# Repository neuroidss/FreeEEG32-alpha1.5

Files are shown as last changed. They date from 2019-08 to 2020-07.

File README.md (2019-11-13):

# FreeEEG32 + alpha1.5
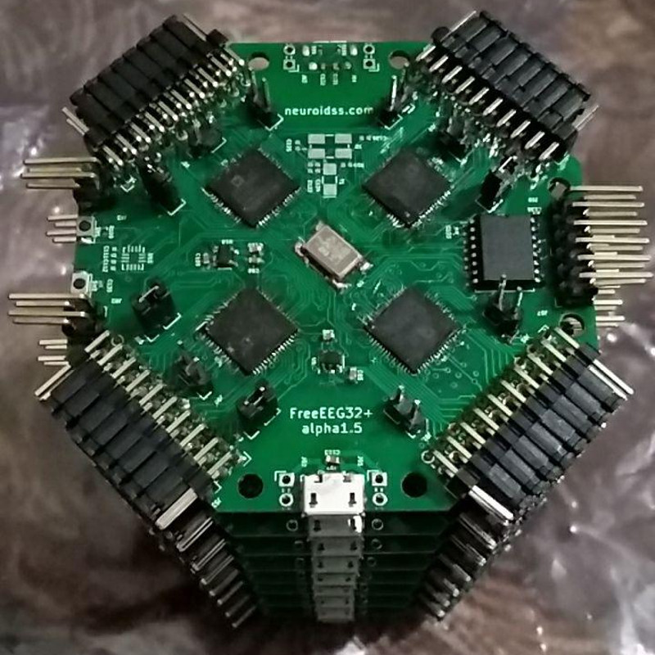
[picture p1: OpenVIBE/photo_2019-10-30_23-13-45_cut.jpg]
8x FreeEEG32 + alpha1.5

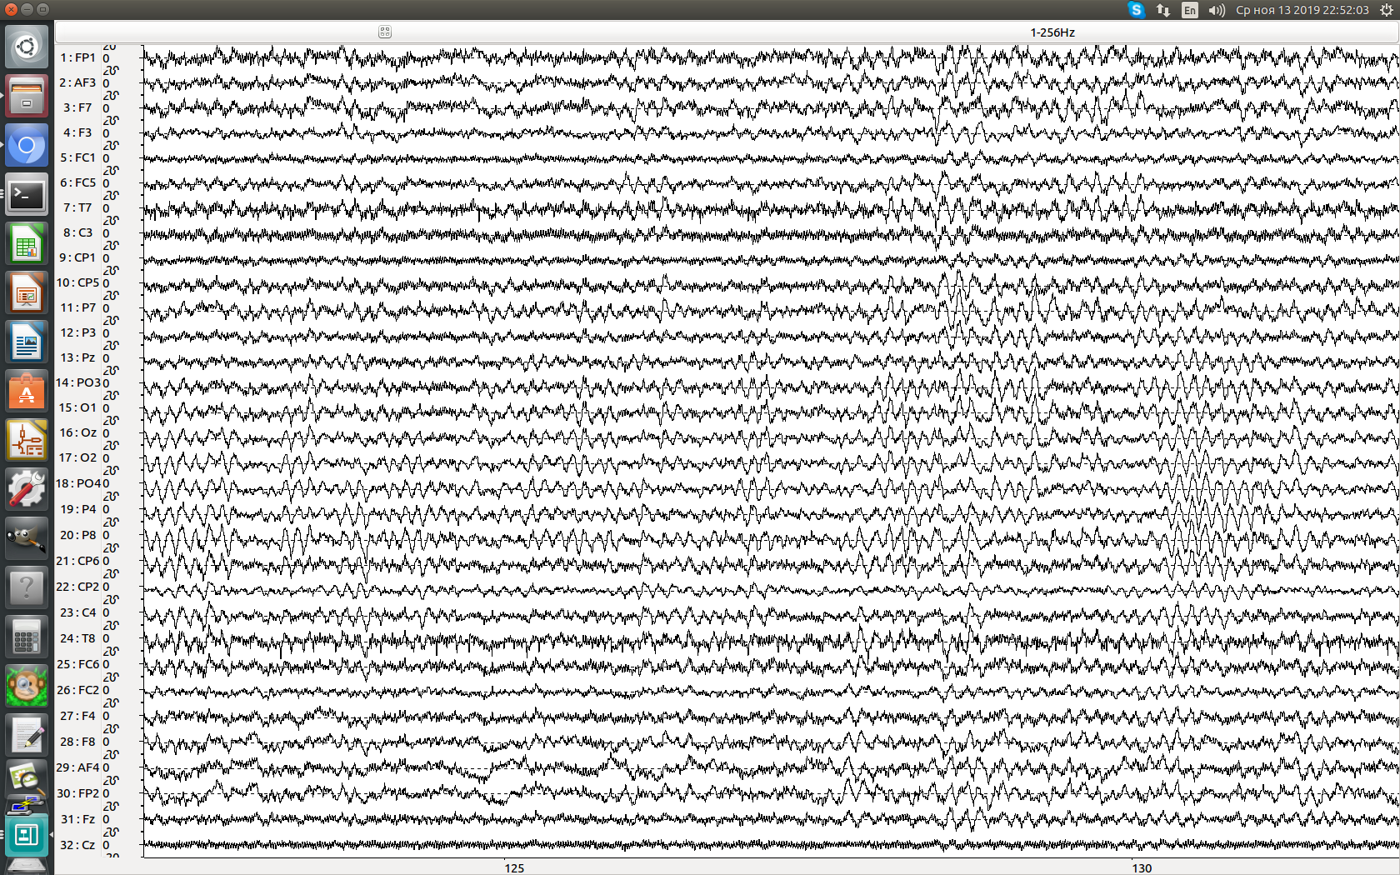
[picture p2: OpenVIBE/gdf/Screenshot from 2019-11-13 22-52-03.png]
OpenVIBE FreeEEG32 + alpha1.5

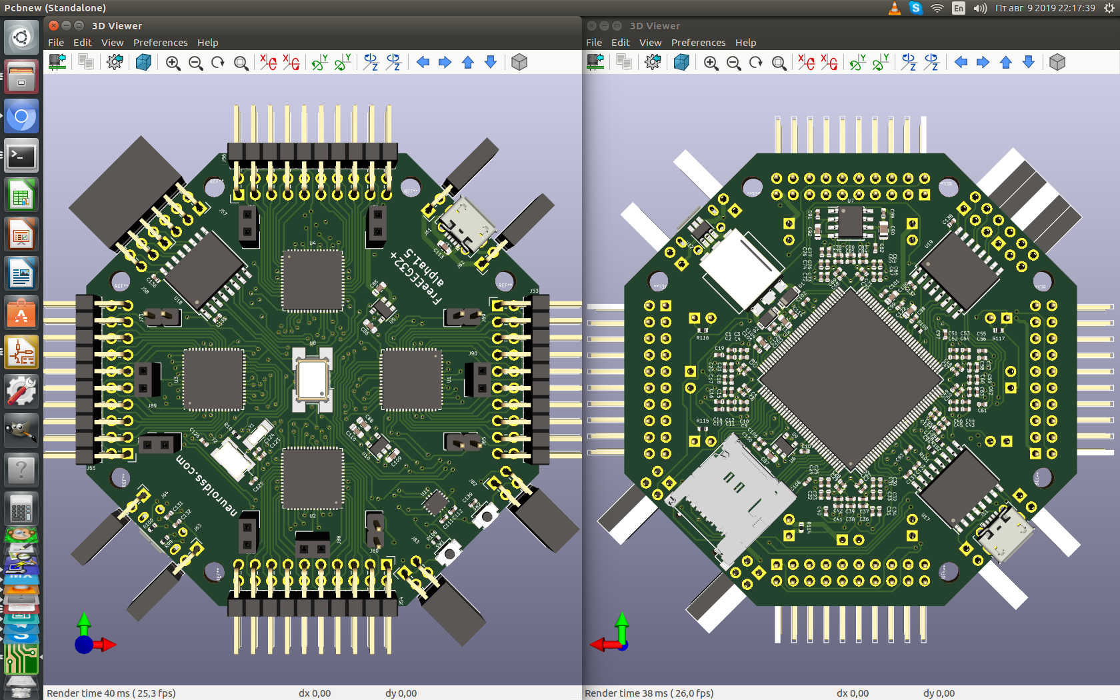
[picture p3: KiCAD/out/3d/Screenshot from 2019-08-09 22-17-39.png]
KiCAD FreeEEG32 + alpha1.5

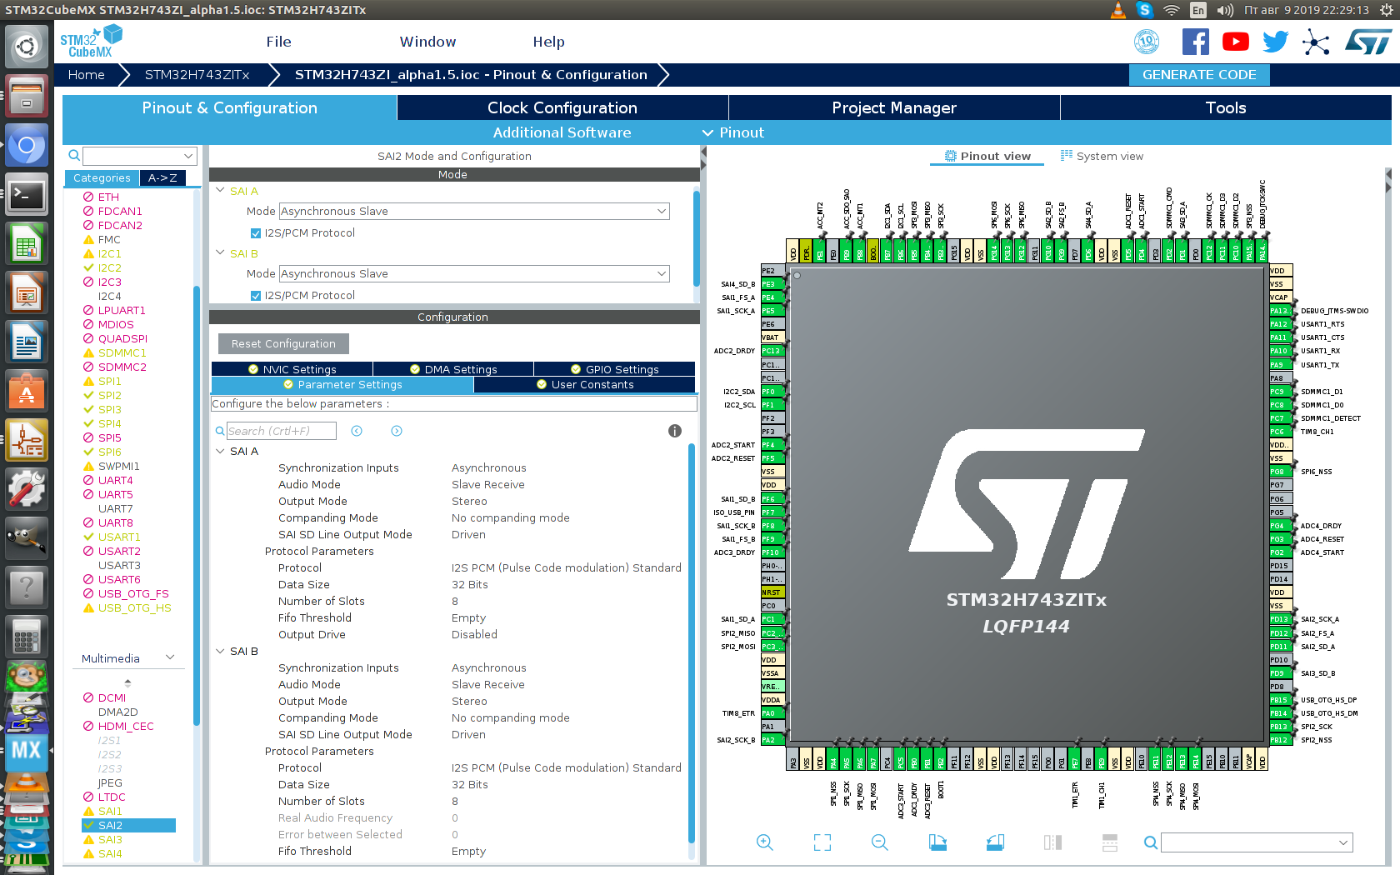
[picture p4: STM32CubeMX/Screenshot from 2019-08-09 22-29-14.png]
STM32CubeMX FreeEEG32 + alpha1.5

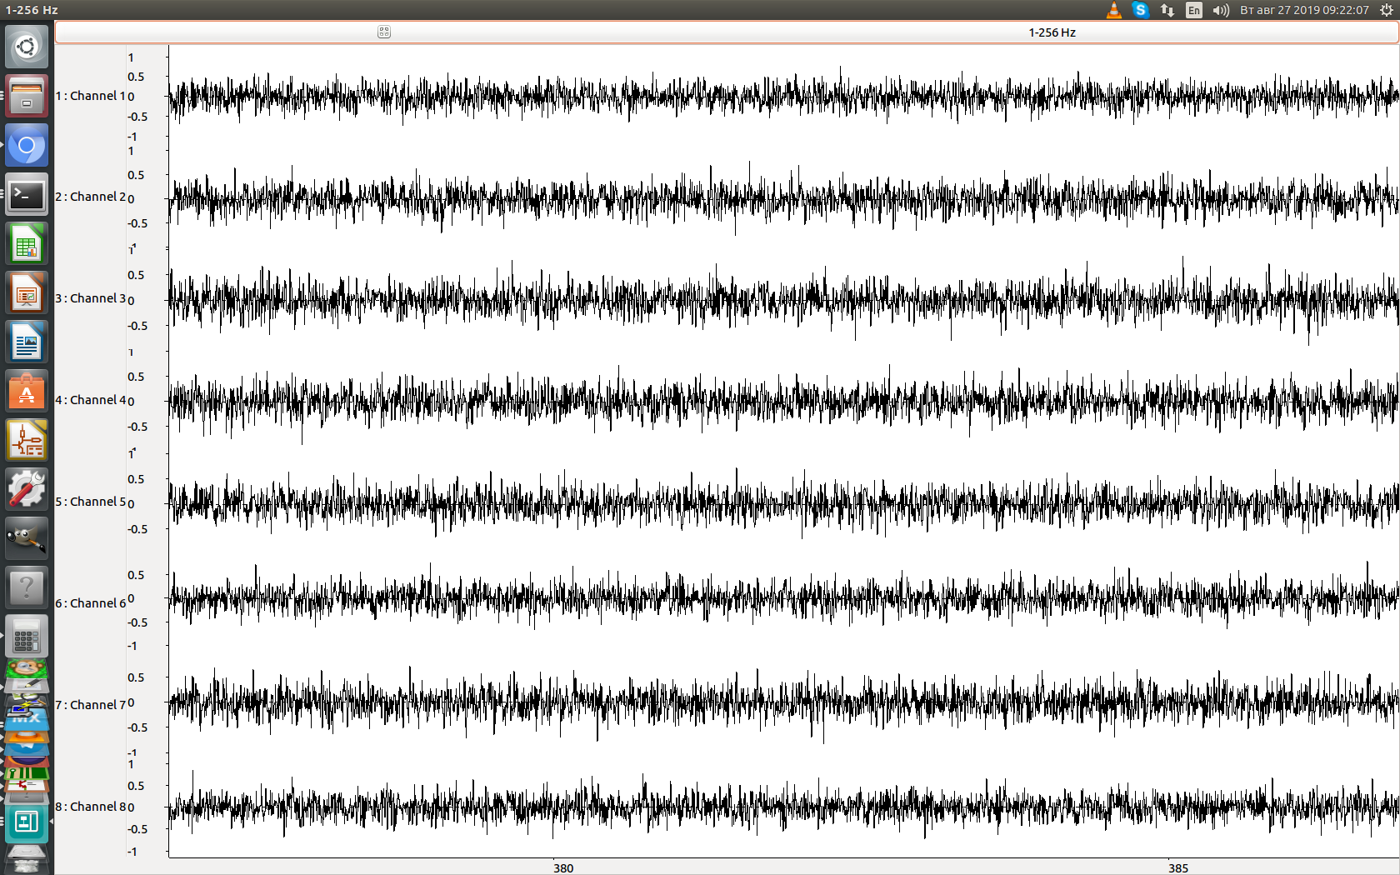
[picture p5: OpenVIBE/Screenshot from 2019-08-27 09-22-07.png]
OpenVIBE FreeEEG32 + alpha1.5

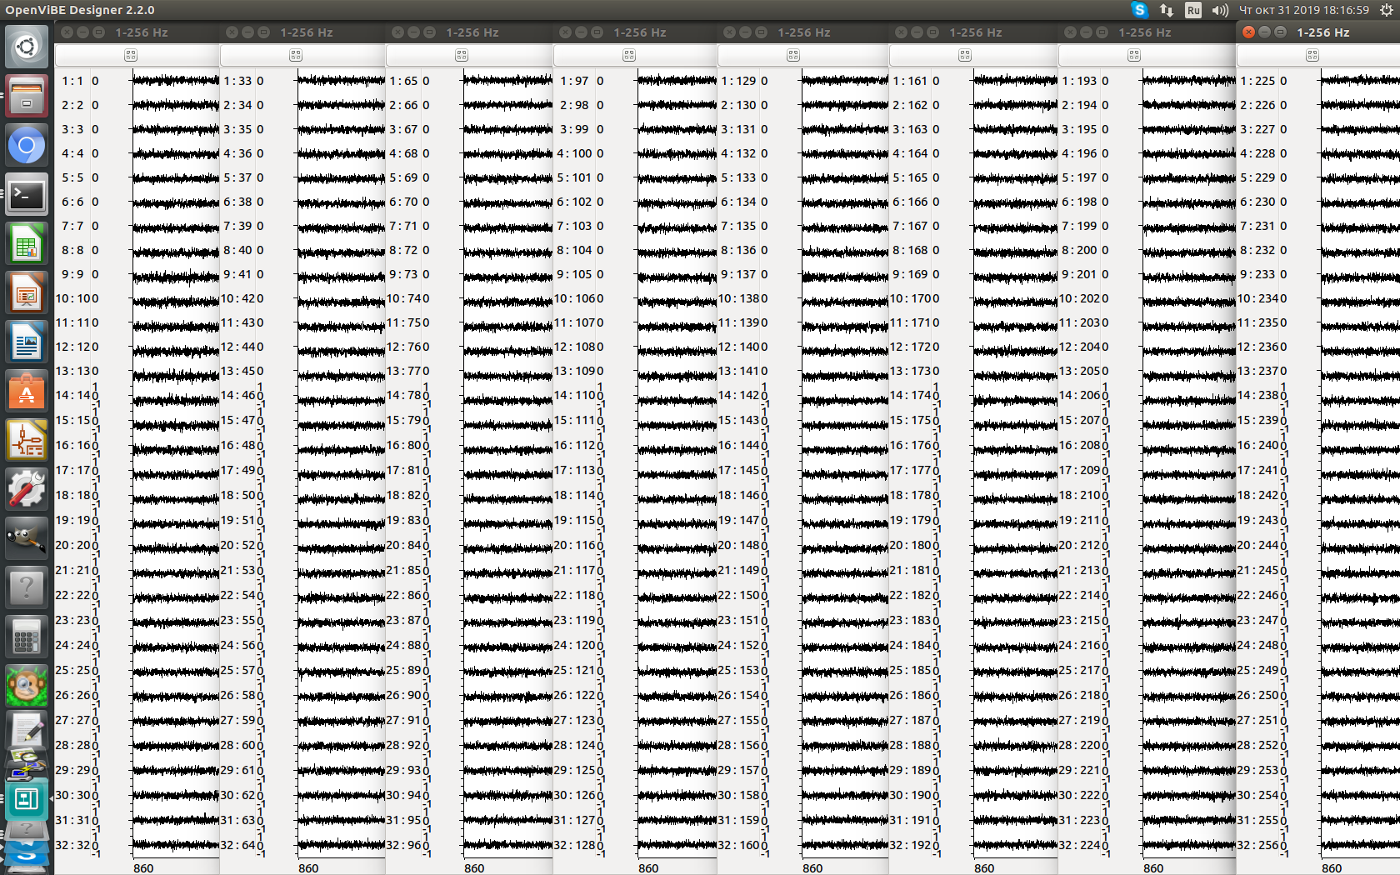
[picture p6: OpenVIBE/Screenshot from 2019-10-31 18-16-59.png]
OpenVIBE 8x FreeEEG32 + alpha1.5


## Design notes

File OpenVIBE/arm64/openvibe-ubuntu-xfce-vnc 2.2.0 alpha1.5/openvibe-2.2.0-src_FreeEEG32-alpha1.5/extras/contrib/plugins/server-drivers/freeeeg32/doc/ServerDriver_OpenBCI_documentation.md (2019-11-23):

OpenViBE logo

OpenBCI logo

# OpenBCI driver for OpenViBE documentation #

(documentation stands for [OpenViBE][OpenViBE] **1.2.0-OpenBCI-RC1**)

## Welcome ##

Welcome in the documentation of the [OpenBCI][OpenBCI] driver for [OpenViBE][OpenViBE]. This document gives you step by step details on how to configure your system, hardware and software to get the best possible experience. For further details about OpenBCI and OpenViBE, please refer to their [respective][OpenBCI] [documentation][OpenViBE].

## Getting Started ##

This section gives guidelines on how to set-up your environment configuration to get the best experience using [OpenBCI][OpenBCI] with [OpenViBE][OpenViBE]

### Linux ###

In order to use the [OpenBCI][OpenBCI] driver on Linux, you need to be granted read/write access to the serial port that is used to communicate with the dongle. Unfortunately, this does not come as a standard configuration on many Linux distributions and you will need to configure your setup so that the user is granted these access. On [Ubuntu][UbuntuDotCom] and its derivative, as well as on [Debian][DebianDotOrg], this can simply be achieved by adding the user to the `dialog` group with the following command :

> sudo adduser *username* dialout

Please note that you may need to close and reopen the session for changes to take effect.

On [Fedora][FedoraDotOrg] and its derivative, a similar command should be used to add the user in the `dialout` group :

> sudo usermode -a -G dialout *username*

Again, please note that you may need to close and reopen the session for changes to take effect.

### Windows ###

It is necessary to walk through a litlle bit of configuration to have the best experience with [OpenBCI][OpenBCI] and [OpenViBE][OpenViBE] on Windows. Indeed, when Windows first installs a serial port, its default configuration is not optimal for realtime streaming of the data. It especially configures large buffering and latencies, causing delays in the communication which eventually lead in delays in the acquired signals. While this only delays the detection of Motor Imagery or SSVEP tasks by a few hundreds of milliseconds, this also delays the ERP (eventually leading to a misdetection) and in all cases, alters the neurophysiological validity of the acquired data by a significant fraction. Consequently, it is recommended to configure the serial ports so that they are suitable for realtime use.

Note that this configuration is necessary each time Windows creates a new serial port. This may unfortunately happen **every time** you move the dongle on a new USB port on the computer !

In order to open the configuration dialog of the serial port, please follow these steps:

- Right click on the `Computer` icon and chose `Manage`
- After the `Computer Management` tool is opened, browse the tree in the left pane to the `Device Manager` section
- After the `Device Manager` tree is opened, browse in the right pane to the `Ports (COM & LPT)` section
- Then double click your port (in my case, `USB Serial Port (COM3)`

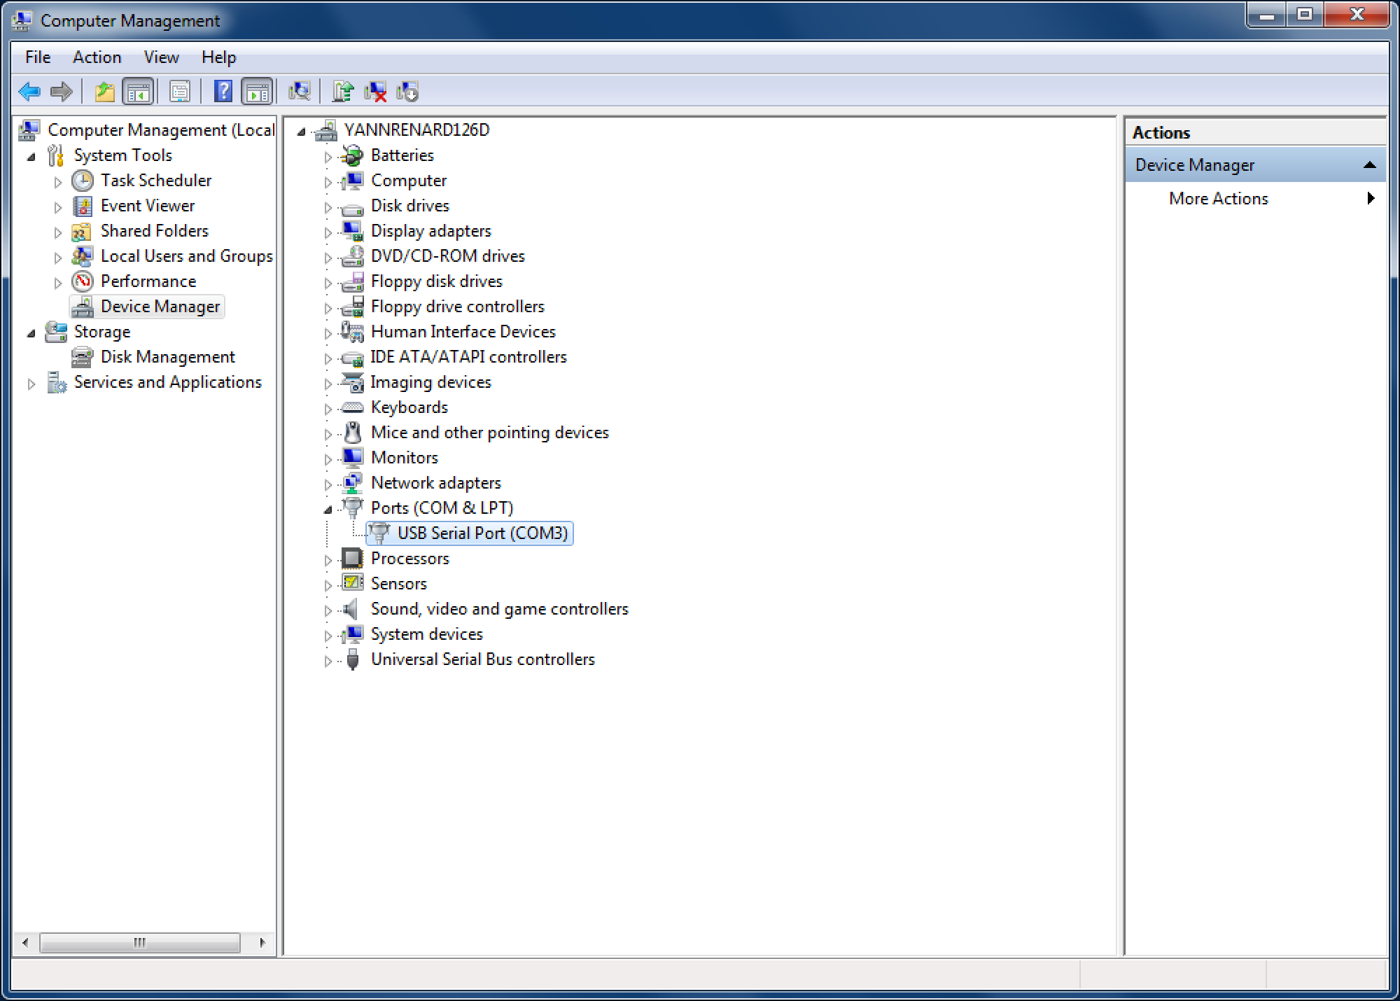
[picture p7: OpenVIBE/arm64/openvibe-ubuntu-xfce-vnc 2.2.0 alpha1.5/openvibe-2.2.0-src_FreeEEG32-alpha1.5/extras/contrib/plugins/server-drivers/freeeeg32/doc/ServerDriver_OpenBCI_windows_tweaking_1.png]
The Windows Device Manager


- In the `USB Serial Port Properties` dialog, go to the `Port Settings` tab and click `Advanced`

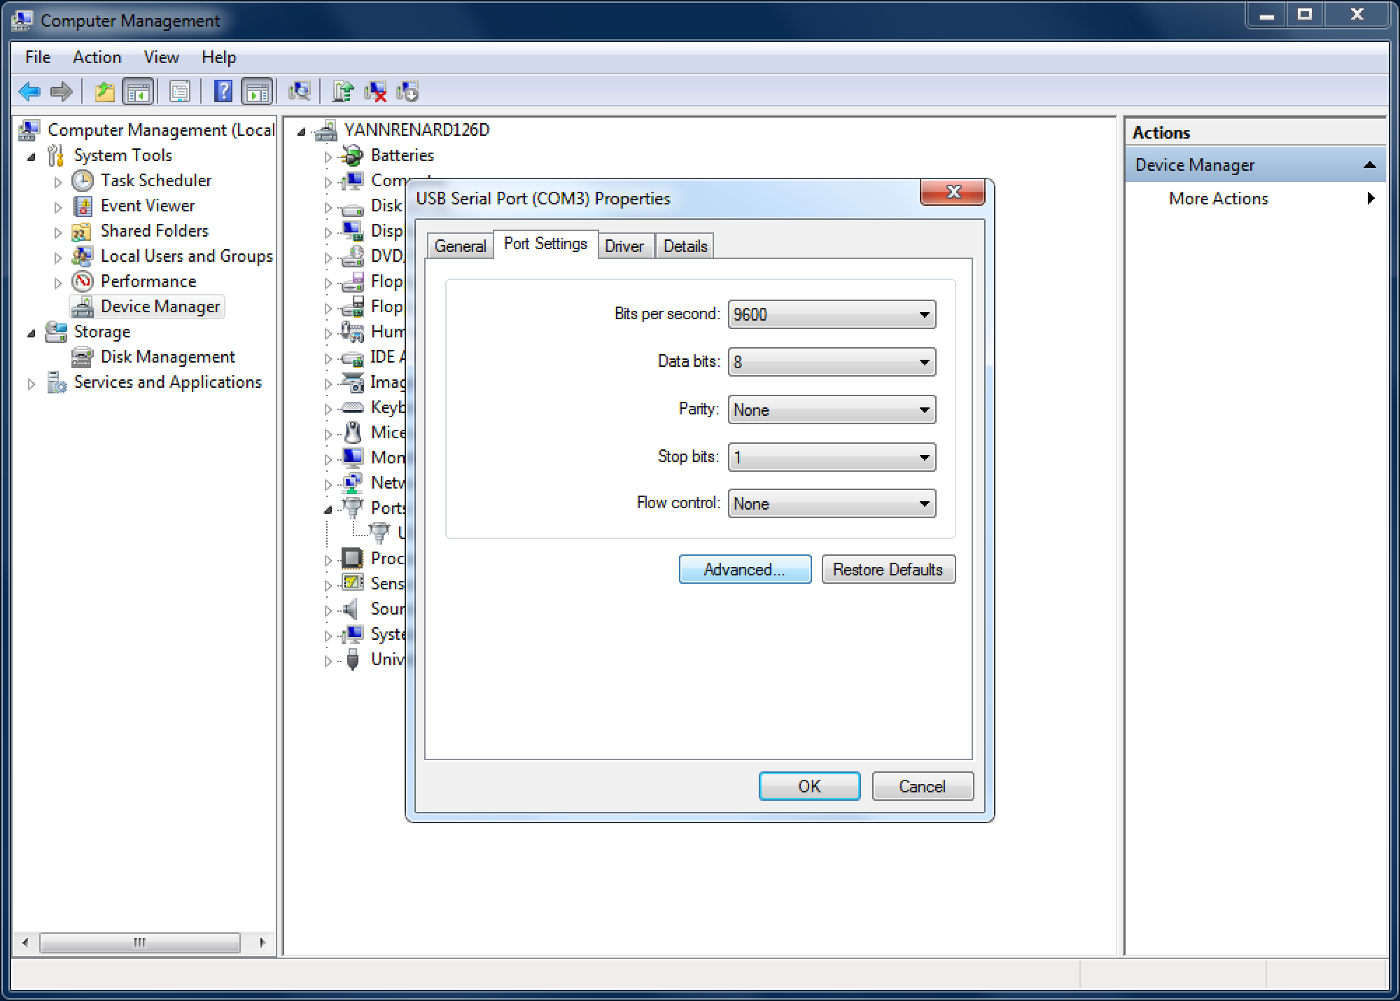
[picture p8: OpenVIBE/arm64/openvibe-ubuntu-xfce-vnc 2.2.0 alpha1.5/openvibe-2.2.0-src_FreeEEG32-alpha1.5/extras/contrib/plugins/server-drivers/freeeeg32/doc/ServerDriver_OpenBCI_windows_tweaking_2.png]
The Port Settings dialog


- This opens the `Advanced Settings for your COM port`

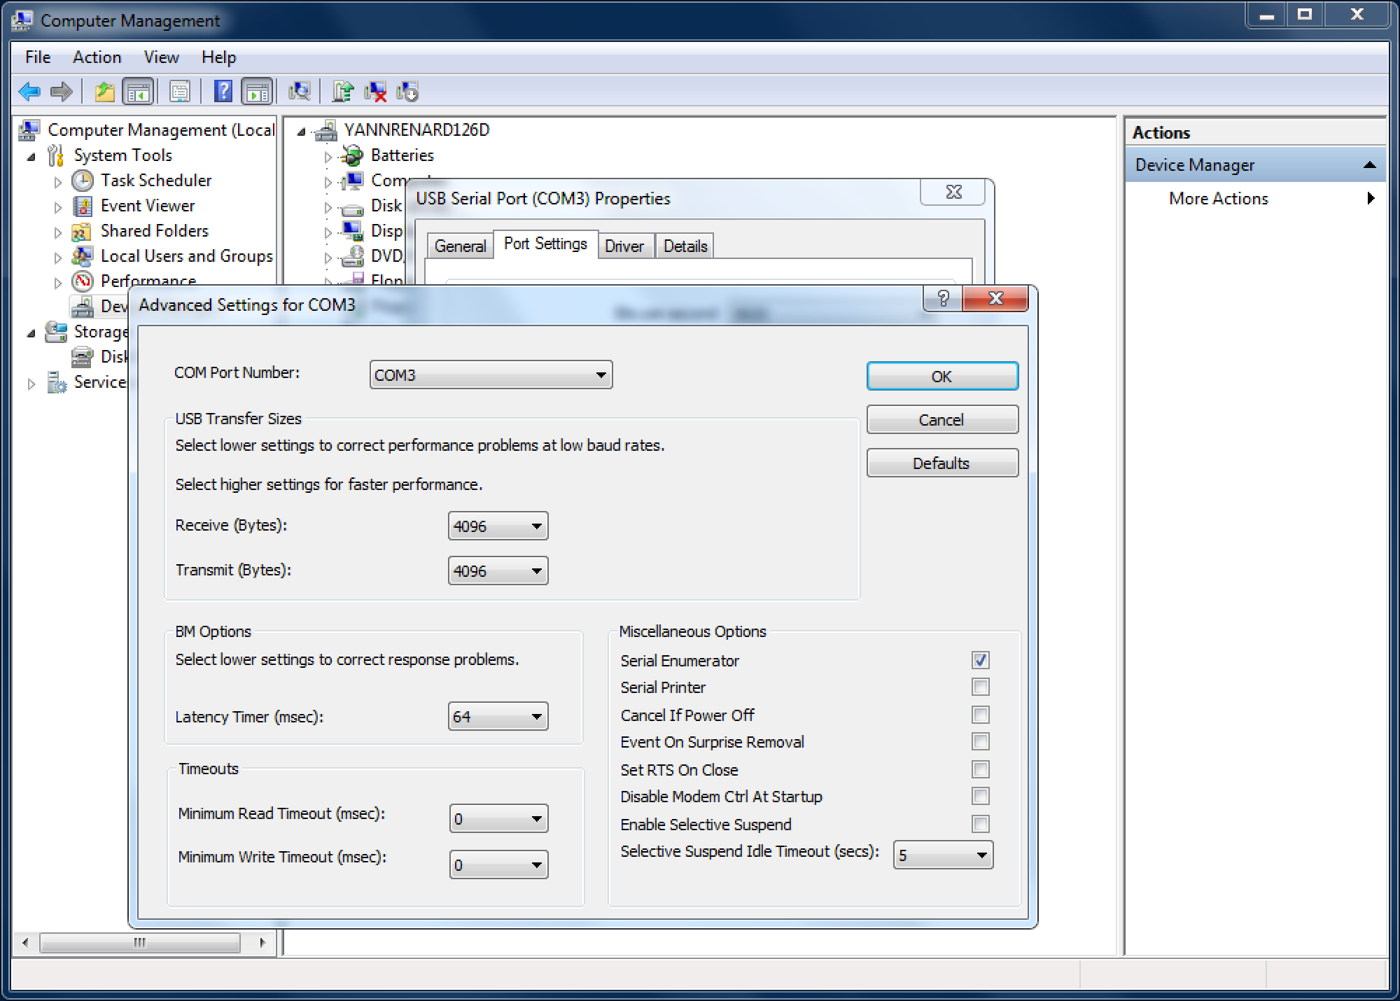
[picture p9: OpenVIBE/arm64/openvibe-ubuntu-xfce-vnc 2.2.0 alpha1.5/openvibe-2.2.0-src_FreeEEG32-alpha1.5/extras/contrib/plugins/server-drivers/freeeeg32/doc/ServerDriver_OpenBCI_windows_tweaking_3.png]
The Advanced Port Settings dialog


From this window, there are three settings we need to change :

- The `Receive` and `Transmit` settings of the `USB Transfer Sizes` section should both be changed from 4096 to **64** as this will reduce the time taken by the OS to deliver the data to either the dongle or the [OpenViBE][OpenViBE] driver
- The `Latency Timer` of the `BM Options` section should be reduced down to **1** as this will dramatically reduce the latency induced by the OS.

After you changed the settings as shown on the following figure, please click `OK`.

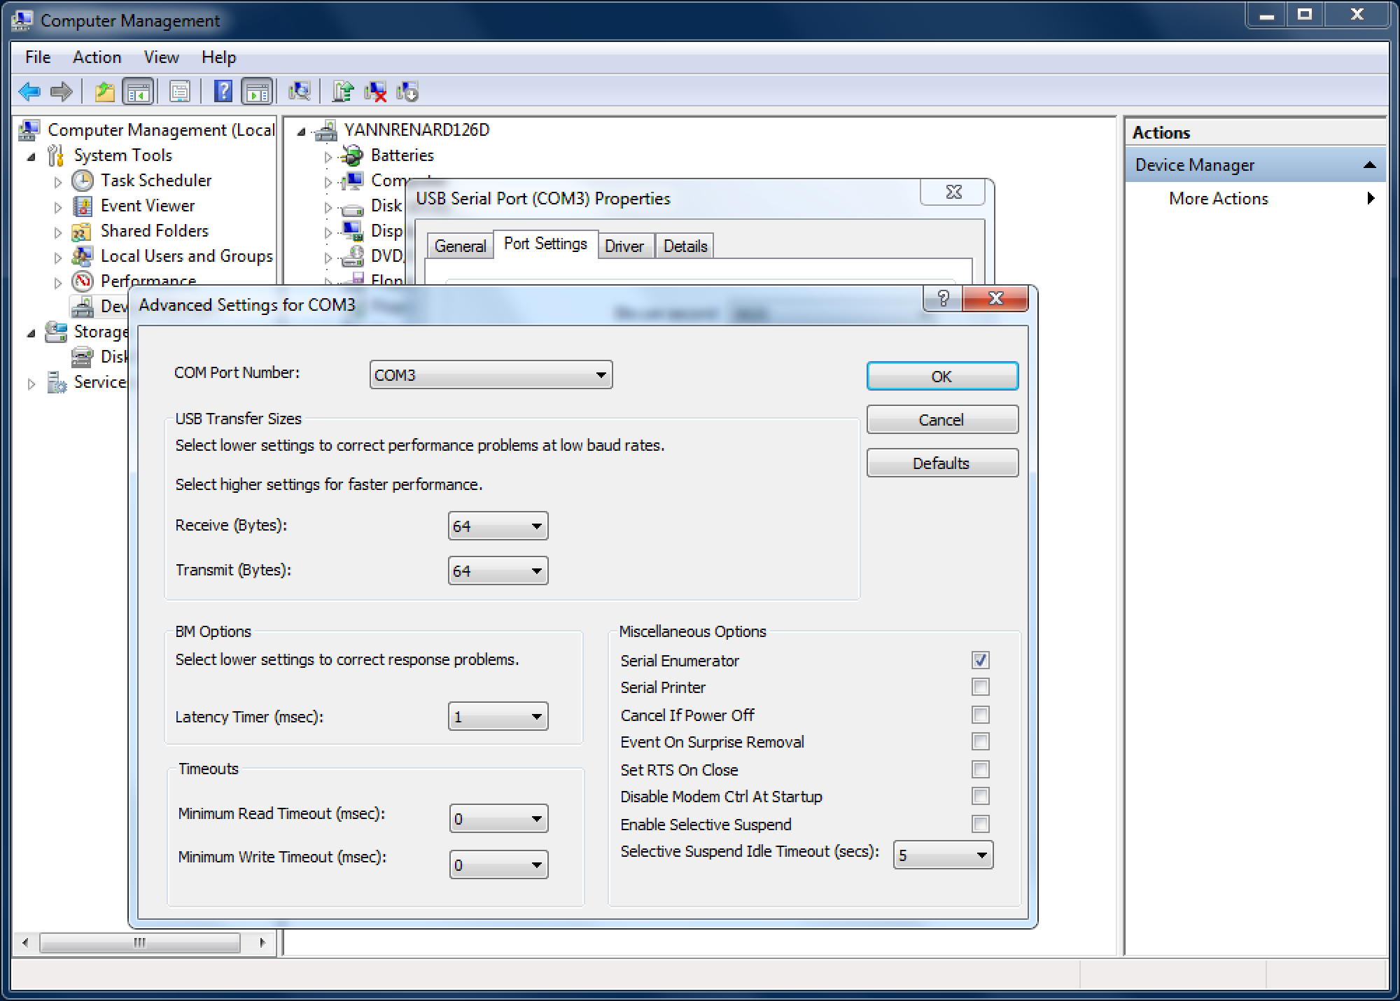
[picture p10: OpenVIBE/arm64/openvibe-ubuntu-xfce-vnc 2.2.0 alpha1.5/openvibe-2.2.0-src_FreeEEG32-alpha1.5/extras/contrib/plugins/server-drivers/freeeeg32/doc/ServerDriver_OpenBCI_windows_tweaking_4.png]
The tweaked configuration of COM ports to have best experienece with OpenViBE and OpenBCI


It is *not necessary* to restart the computer for the changes to take effect.

## Configuration ##

The configuration dialog of the [OpenBCI][OpenBCI] driver comes with a number of settings that one can change or pick depending on his preference.

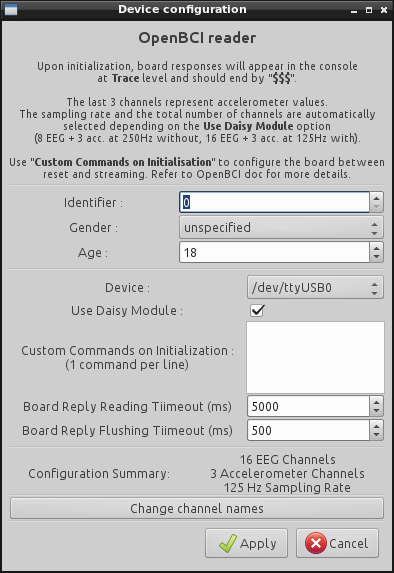
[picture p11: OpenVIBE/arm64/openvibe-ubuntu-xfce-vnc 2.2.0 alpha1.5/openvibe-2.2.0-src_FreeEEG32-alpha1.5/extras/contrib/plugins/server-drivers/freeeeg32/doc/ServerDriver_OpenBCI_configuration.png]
The OpenBCI configuration dialog


The following table documents each option that is specific to the [OpenBCI][OpenBCI] device. Please refer to the [OpenViBE documentation][OpenViBEDoc] for anything generic to the [OpenViBE][OpenViBE] Acquisition Server.

| Option | Default Value | Documentation |
| :---: | :---: | :---|
| **Device** | *empty* | This allows you to pick a serial port to connect on. The drodown list shows the serial ports that can currently be opened on this computer. If no port is found, the mention *No valid serial port* is shown in this list. If you cannot find your device in this list, please refer  . |
| **Use Daisy Module** | *false* | This allows you to configure the daisy module. Four cases should be considered. 1/ if the daisy module is present and this option is set to **true**, then the device will turn to 16 channels samples 125 Hz. 2/ if no daisy module is present and this option is set to **false**, then the device will turn to 8 channels, 250 Hz. 3/ if the daisy module is **not present** on the board and this option is set to **true**, then the initialization of the driver will **fail**. 4/ if the daisy module is **present** on the board and this option is set to **false**, the daisy module will be disabled and the acquisition will be done as if the daisy module was not present on the board, turning the device back to 8 channels sampled at 125 Hz. |
| **Custom Command On Initialization** | *empty* | This option contains additional commands to send to the device at initialization. You must use one line per command, some command may contain multiple characters. For details about the commands, please refer to the [OpenBCI protocol documentation][OpenBCIProto]. Be advised that this will increase the delay of initialization by an order of magnitude that is a direct relation of the number and types of commands you want to add. Finally, not all the commands take the same time to be executed, if you include custom commands, you should consider adjusting the timeout values. |
| **Board Reply Reading Timeout** | 5000 | This allows to define the maximum time until reading a reply from the board after sending a command times out. Many commands end with a **\$\$\$** pattern, which can handily be captured and release the waiting loop when reading the board reply, but not all the commands have this **\$\$\$** pattern. Consequently, it is necessary to have a timeout for the other commands. The default value has been chosen to behave well even with custom commands that need a long time to reply such as **?**. If you don't use such command in your *Custom Command On Initialization*, you may reduce that delay. But be aware that if you reduce it too much, the driver may miss the **\$\$\$** pattern even though the board has sent it, resulting in unexpected behavior. |
| **Board Reply Flushing Timeout** | 500 | This option allows to flush and get rid of the streaming buffer. This is especially used when the driver asks the board to stop streaming and makes the streaming state absolutely clean when the driver needs to send a new command after stopping the streaming. You may reduce this value to make (re)connection faster, but if the buffer came not to be completely flushed, the remaining would be taken as the begining of the next command and this may result in unexpected behavior. |

The Configuration Summary gives information on the current configuration, especially the number of channels and the sampling rate of the device.

## Advanced Configuration ##

In addition to the above settings, another few settings are available to the user as advanced configuration. They are not exposed in the GUI and should be directly set in the [OpenViBEConfig][OpenViBE configuration] file instead. Refere to the [Configuration Manager section][OpenViBEConfig] of the [OpenViBE documentation][OpenViBEDoc] for further details on the configuration file format, location and others.

| Token | Default Value | Documentation |
| :---: | :---: | :---|
| **AcquisitionDriver OpenBCI MissingSampleDelayBeforeReset** | *1000* | This defines the size of the window to continuously monitor reception of samples from the driver. If no sample is received within that timeframe, the board is requested to stop and restart streaming. While the non-reception of samples from the board may reflect an unexpected state in the board, this strategy seems to sometimes recover and let the streaming go back to normal. The default value allows a good compromise between dealing with buffering and actual transmission delays and recovering fast when something goes wrong. If you experience such unstability in the transmision, we recommend that you first explore anything that may (in)directly affect the quality of the transmission before tweaking this setting. |
| **AcquisitionDriver OpenBCI DroppedSampleCountBeforeReset** | *5* | This defines the number of sample loss events until a recovery is attempted. It happens that the board gets in an unstable state where some sample would be missing in the stream. Stopping and restarting the streaming has proved to recover well. The default setting has been set so that a few occasional sample loss may occur (due to e.g. quality transmission) and be corrected by the drift correction process, while not waiting too long to attempt recovery when too many sample are lost. |
| **AcquisitionDriver OpenBCI DroppedSampleSafetyDelayBeforeReset** | *1000* | This defines a sefety delay where no reset should be attempted because of sample loss (see **AcquisitionDriver OpenBCI DroppedSampleCountBeforeReset**). This prevents a reset on the first sample where the driver synchronises with the streaming protocol and may miss a few samples until it is perfectly synced with the header and tail of the protocol frame. |

[FedoraDotOrg]: http://www.fedora.org
[UbuntuDotCom]: http://www.ubuntu.com
[DebianDotOrg]: http://www.debian.org

[OpenViBE]: http://openvibe.inria.fr
[OpenViBEDoc]: http://openvibe.inria.fr/documentation-index
[OpenViBEConfig]: http://openvibe.inria.fr/the-configuration-manager
[OpenViBELogo]: http://openvibe.inria.fr/openvibe/wp-content/themes/openvibe/images/openvibe-banner.png

[OpenBCI]: http://docs.openbci.com
[OpenBCIProto]: http://docs.openbci.com/software/01-OpenBCI_SDK
[OpenBCILogo]: http://openbci.com/community/wp-content/uploads/2015/09/logo_wide_web_borders_BIG-copy-1024x137.png

[WindowsTweaking1]: ServerDriver_OpenBCI_windows_tweaking_1.png
[WindowsTweaking2]: ServerDriver_OpenBCI_windows_tweaking_2.png
[WindowsTweaking3]: ServerDriver_OpenBCI_windows_tweaking_3.png
[WindowsTweaking4]: ServerDriver_OpenBCI_windows_tweaking_4.png
[DriverDialog]: ServerDriver_OpenBCI_configuration.png

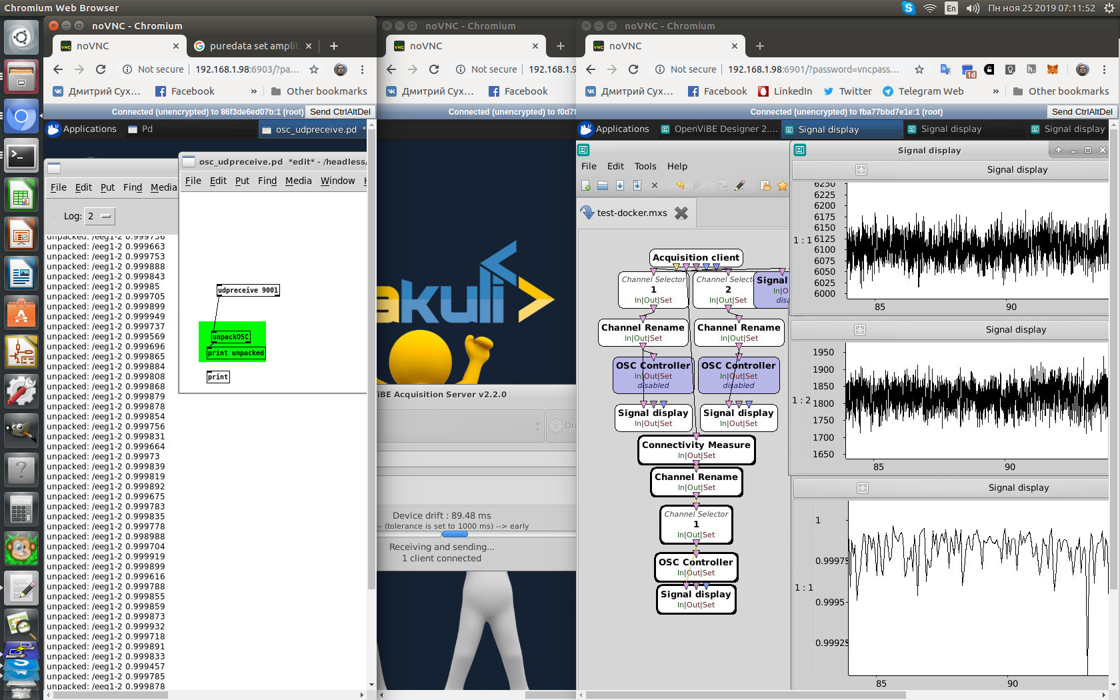
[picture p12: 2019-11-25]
OpenVIBE/Screenshot from 2019-11-25 07-11-53.png

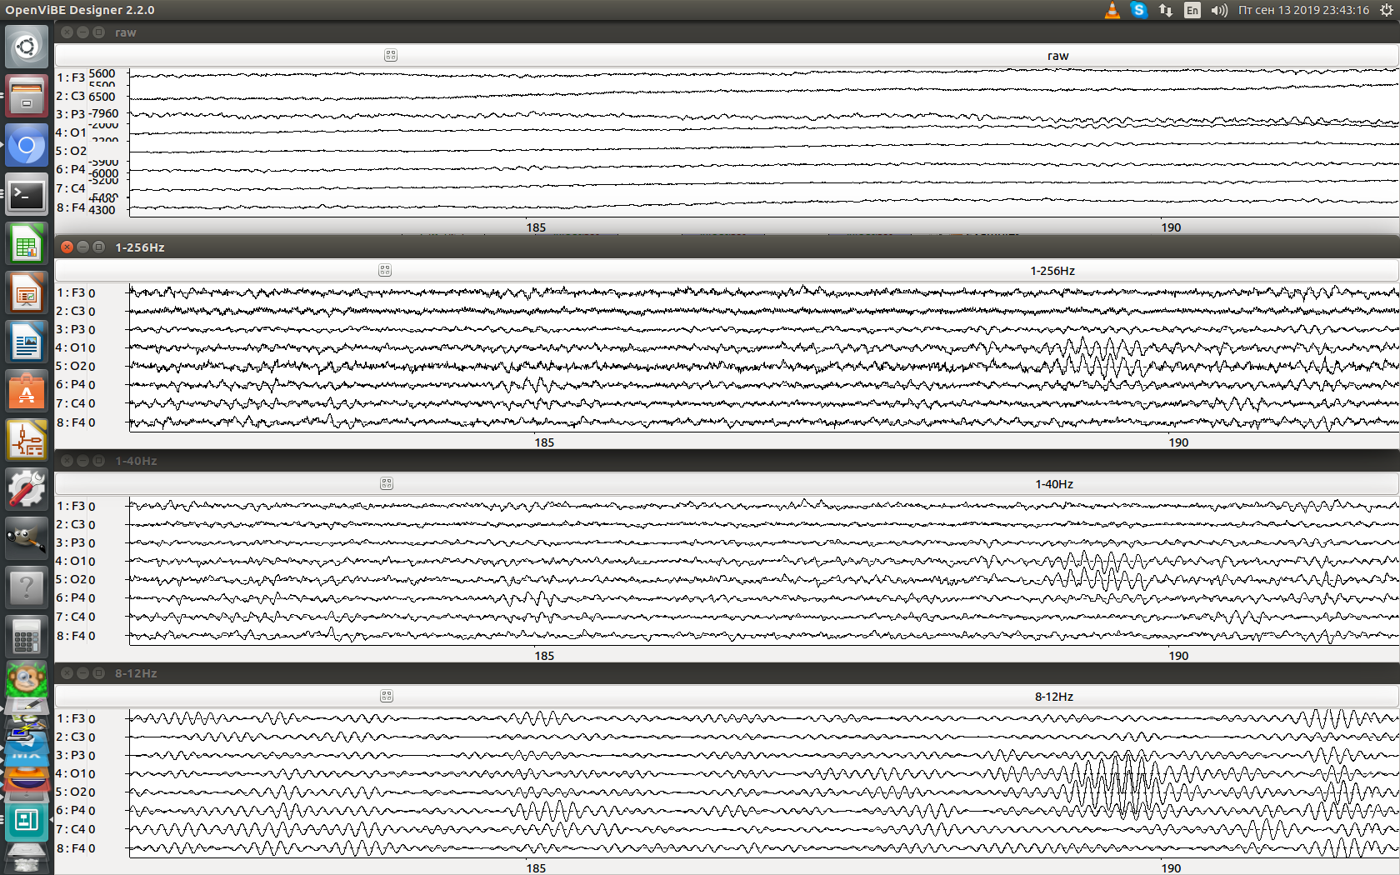
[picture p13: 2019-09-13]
OpenVIBE/gdf/Screenshot from 2019-09-13 23-43-16.png

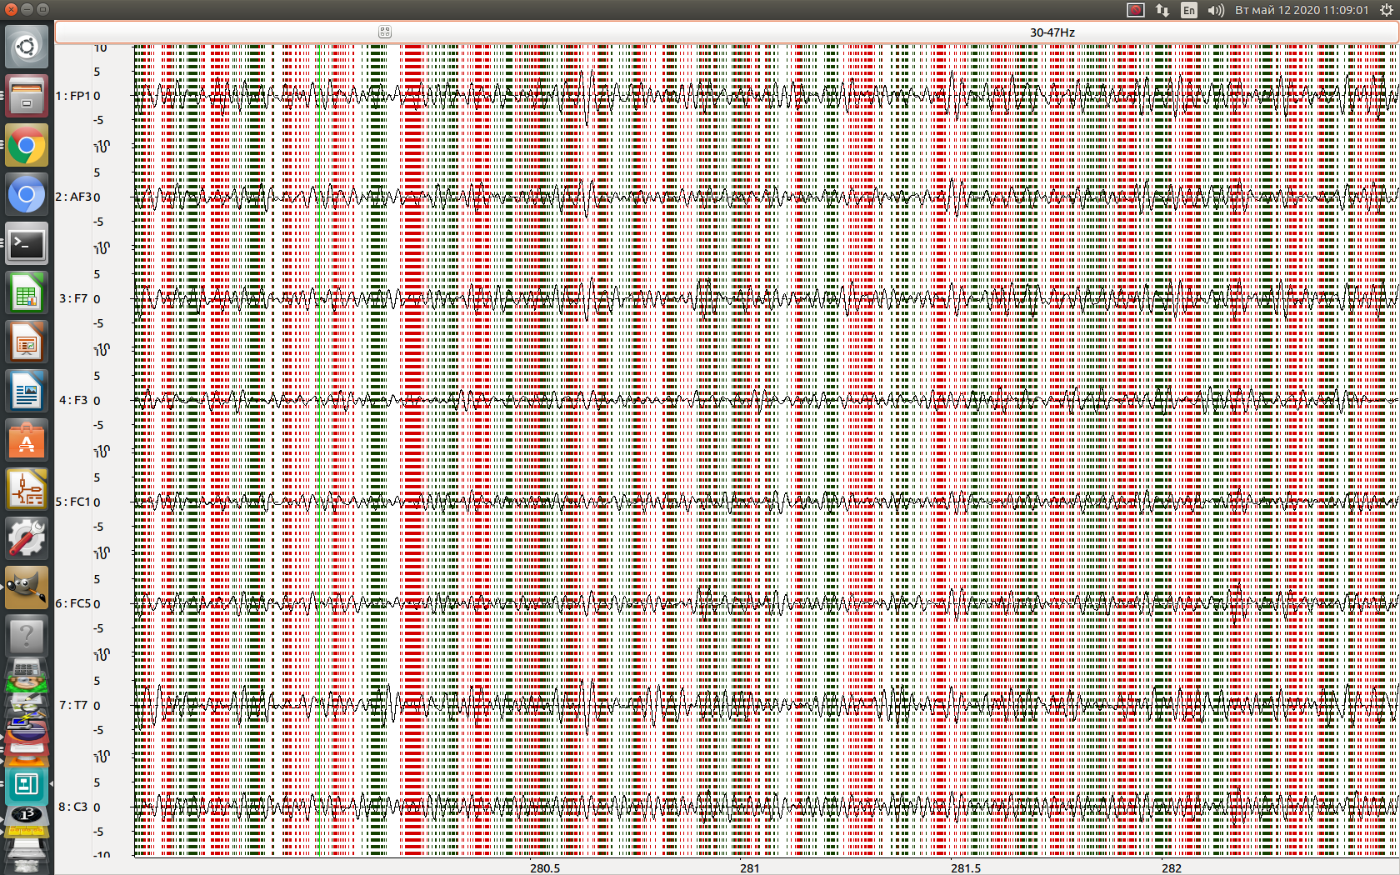
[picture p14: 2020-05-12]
theta&gamma2octave/Screenshot from 2020-05-12 11-09-02.png

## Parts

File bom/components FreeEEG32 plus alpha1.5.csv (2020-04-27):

Designator | Manufacturer Part Number or Seeed SKU | Qty | Link | Description | alt
U1,U2,U4,U3 | AD7771BCPZ | 4 |  | IC ADC 24BIT SIGMA-DELTA 64LFCSP
U7 | ADR4525BRZ | 1 |  | IC VREF SERIES 2.5V 8SOIC
U18 | ADUM1402BRWZ | 1 |  | digital isolator 10Mbps 2.7÷5.5VDC SMD SO16-W | ADUM142E1BRWZ
U17 | ADUM3160BRWZ | 1 |  | Digital Isolator CMOS 2-CH 12Mbps 16-Pin SOIC W Tube
U8 | CB3LV-3I-8M1920 | 1 |  | XTAL OSC XO 8.1920MHZ HCMOS TTL
Y1 | FC-135 32.7680KA-A5 | 1 |  | CRYSTAL 32.7680 KHZ 12.5PF SMD
J53,J56,J55,J54 | 68021-220HLF | 4 |  | CONN HEADER R/A 20POS 2.54MM
C122 | C0603C475K9PACTU | 1 |  | CAP CER 4.7UF 6.3V 10% X5R 0603
J37,J51 | 105017-1001 | 2 |  | CONN RCPT USB2.0 MICRO B SMD R/A
U13 | 47352-1001 | 1 |  | CONN MICRO SD CARD PUSH-PUSH R/A
C125,C123,C126,C124 | GRM1555C1H200JA01D | 4 |  | CAP CER 20PF 50V C0G/NP0 0402
C113,C92,C115 | GRM188R60J106ME47D | 3 |  | CAP CER 10UF 6.3V 20% X5R 0603
C85,C110,C104,C100,C88,C87,C86,C109 | GRM188R71A225KE15D | 8 |  | CAP CER 2.2UF 10V 10% X7R 0603
C90 | GRM21BR60J226ME39L | 1 |  | Multilayer Ceramic Capacitors MLCC Surface Mount 0805 22uF 6.3 Volts X5R 20%
SW1,SW2 | B3U-1000P | 2 |  | Switch Tactile N.O. SPST Round Button Gull Wing 0.05A 12VDC 1.5N SMD Embossed T/R
D1,D2 | MBR0520LT1G | 2 |  | Rectifier, Schottky Power; Plastic Sod-123; 0.5 a @ +90c If; +125; 20v; 1000
C81,C10,C12,C127,C128,C129,C130,C16,C18,C2,C21,C23,C25,C27,C29,C31,C33,C37,C39,C4,C42,C46,C48,C50,C52,C54,C58,C6,C60,C63,C65,C67,C69,C71,C73,C75,C79,C8,C84,C44 | CL05A105KO5NNNC | 40 |  | CAP CER 1UF 16V X5R 0402
C98,C1,C101,C102,C103,C105,C106,C107,C108,C11,C111,C112,C114,C13,C131,C132,C133,C134,C135,C136,C137,C138,C14,C15,C17,C19,C20,C22,C24,C26,C28,C3,C30,C32,C34,C35,C36,C38,C40,C41,C45,C47,C49,C5,C51,C53,C55,C56,C57,C59,C61,C62,C64,C66,C68,C7,C70,C72,C74,C76,C77,C78,C80,C82,C83,C9,C91,C93,C94,C95,C96,C97,C99,C43,C89,C139 | CL05B104KO5NNNC | 76 |  | CAP CER 0.1UF 16V X7R 0402
J85,J88,J89,J90,J79,J81,J78 | SSQ-102-03-G-S | 7 |  | CONN RCPT 2POS 0.1 TIN PCB | SSQ-102-03-G-S | ED4264-02-ND | SSA-102-W-T | ED5764-02-ND | SSQ-102-03-T-S | 316-43-102-41-003000 | 316-93-102-41-008000 | SS-102-TT-2 | 310-87-102-41-001101 | 801-87-002-10-001101 | 311-43-102-41-001000
J65,J80,J73,J69 | PRPC001DAAN-RC | 4 |  | CONN HEADER VERT 2POS | PRPC001DAAN-RC | TSW-101-07-F-D | A26564-ND | GEC01DAAN
U11 | LSM6DSOXTR | 1 |  | IMU ACCEL/GYRO I2C/SPI 14TFLGA | LSM6DS3TR | LSM6DSRXTR | LSM6DSOXTR
U9 | STM32H743ZIT6U | 1 |  | HIGH-PERFORMANCE AND DSP WITH DP
J62,J63,J64,J61 | 68021-402HLF | 4 |  | CONN HEADER R/A 2POS | PREC001DBAN-M71RC | TSW-101-08-T-D-RA | PEC01DBAN | 9-103795-0-01 | 68021-402HLF | HTSW-101-08-T-D-RA
J83,J82 | 68021-404HLF | 2 |  | CONN HEADER R/A 4POS 2.54MM | PREC002DBAN-M71RC | M20-9950245 | TSW-102-08-T-D-RA | HTSW-102-08-T-D-RA | 68021-404HLF
J57,J58 | 68021-406HLF | 2 |  | CONN HEADER R/A 6POS 2.54MM | PREC003DBAN-M71RC | PH2RA-06-UA | TSW-103-08-T-D-RA |  | 68021-406HLF
U19 | ISO7341CDW | 1 |  | DGTL ISO 3KV 4CH GEN PURP 16SOIC | ADUM141E1BRWZ
U5,U6,U10 | LP5907QMFX-3.3Q1 | 3 |  | IC REG LINEAR 3.3V 250MA SOT23-5 | ADP7118AUJZ-3.3-R7
U12 | SN6505BDBVR | 1 |  | IC TRANSFORMER DRIVER 6SOT-23
Y2 | 7B-16.000MEEQ-T | 1 |  | CRYSTAL 16.0000MHZ 10PF SMD
T1 | 750315371 | 1 |  | XFRMR FWD P-P DC/DC CONV SMD
R102,R100,R101,R99 | RC0402FR-0724RL | 4 |  | RES SMD 24 OHM 1% 1/16W 0402
R10,R114,R116,R117,R115 | RC0402JR-070RL | 5 |  | RES 0.0 OHM 1/16W JUMP 0402 SMD
R109,R108 | RC0402JR-074K7L | 2 |  | RES 4.7K OHM 1/16W 5% 0402 SMD

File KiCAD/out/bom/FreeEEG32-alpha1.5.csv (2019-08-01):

Id | Designator | Package | Quantity | Designation | Supplier and ref
1 | J63,J61,J62,J64 | PinSocket_1x02_P2.54mm_Vertical | 4 | Conn_01x02
2 | Y1 | Crystal_SMD_EuroQuartz_EQ161-2Pin_3.2x1.5mm_HandSoldering | 1 | 32768Hz
3 | T1 | SMT Power Transformer | 1 | da2303
4 | U7 | SOIC-8_3.9x4.9mm_P1.27mm | 1 | ADR4525
5 | D2,D1 | SOD−123 | 2 | D_Schottky
6 | U13 | 473521001 | 1 | 473521001
7 | J58,J57 | PinSocket_2x03_P2.54mm_Vertical | 2 | Conn_02x03_Odd_Even
8 | J51,J37 | USB_Micro-B_Molex-105017-0001 | 2 | USB_B_Micro
9 | C104,C86,C85,C109,C110,C88,C87,C100 | C_0603_1608Metric | 8 | 2.2u
10 | U1,U2,U3,U4 | QFN-64-1EP_9x9mm_P0.5mm_EP7.3x7.3mm | 4 | AD7779
11 | U17 | SOIC-16W_7.5x10.3mm_P1.27mm | 1 | ADuM3160
12 | U9 | LQFP-144_20x20mm_P0.5mm | 1 | STM32F765ZITx
13 | U18 | SOIC-16W_7.5x10.3mm_P1.27mm | 1 | ADUM1402BRWZ
14 | REF**,REF**,REF**,REF**,REF**,REF** | MountingHole_3.2mm_M3 | 6 | MountingHole_3.2mm_M3
15 | U19 | SOIC-16W_7.5x10.3mm_P1.27mm | 1 | ISO7341c
16 | C33,C31,C42,C29,C23,C25,C73,C67,C71,C65,C84,C75,C52,C44,C46,C63,C50,C54,C10,C12,C6,C18,C128,C48,C60,C58,C39,C27,C69,C81,C79,C16,C37,C2,C4,C8,C21,C127,C129,C130 | C_0402_1005Metric | 40 | 1u
17 | C14,C13,C34,C35,C76,C77,C91,C89,C40,C32,C28,C22,C30,C24,C41,C83,C82,C74,C70,C72,C66,C64,C56,C62,C55,C49,C51,C45,C61,C43,C53,C5,C17,C96,C47,C59,C57,C38,C26,C80,C68,C1,C3,C7,C20,C19,C11,C9,C93,C97,C98,C99,C102,C103,C105,C106,C107,C95,C94,C108,C101,C114,C112,C111,C131,C132,C133,C134,C135,C136,C137,C138,C78,C15,C36,C139 | C_0402_1005Metric | 76 | 100n
18 | Y2 | Crystal_SMD_EuroQuartz_MJ-4Pin_5.0x3.2mm_HandSoldering | 1 | 16MHz
19 | U8 | Oscillator_SMD_EuroQuartz_XO91-4Pin_7.0x5.0mm_HandSoldering | 1 | FXO-SM7_OSC-SMD7050_short
20 | U5,U10,U6 | SOT-23-5 | 3 | LP5907
21 | C92,C113,C115 | C_0603_1608Metric | 3 | 10u
22 | C90 | C_0805_2012Metric | 1 | 22u
23 | U12 | SOT-23-6_Handsoldering | 1 | SN6505A
24 | C122 | C_0603_1608Metric | 1 | 4.7u
25 | U11 | Bosch_LGA-14_3x2.5mm_P0.5mm | 1 | LSM6DS3
26 | C123,C125 | C_0402_1005Metric | 2 | CL1
27 | C124,C126 | C_0402_1005Metric | 2 | CL2
28 | R10 | R_0402_1005Metric | 1 | R_EXT
29 | R99,R100,R101,R102 | R_0402_1005Metric | 4 | 20
30 | J53,J54,J55,J56 | PinHeader_2x10_P2.54mm_Horizontal | 4 | Conn_02x10_Odd_Even
31 | J59,J60 | PinSocket_1x03_P2.54mm_Vertical | 2 | Conn_01x03
32 | R108,R109 | R_0402_1005Metric | 2 | 4k7
33 | SW1,SW2 | SW_SPST_B3U-1000P-B | 2 | SW_Push

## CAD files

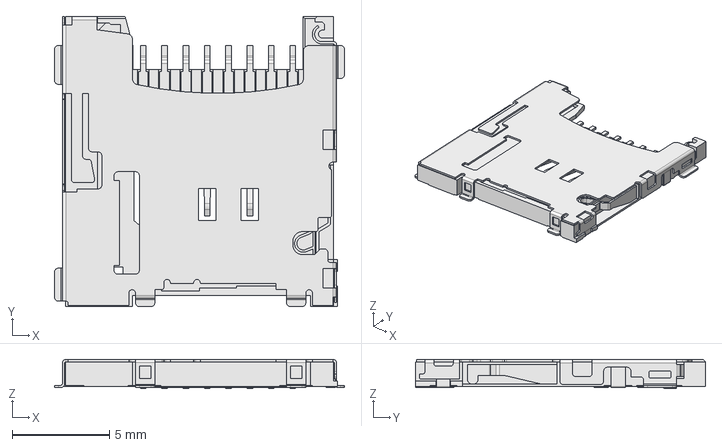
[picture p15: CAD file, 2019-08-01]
KiCAD/3d/Connectors/5031821852.step
14.9 x 14.9 x 1.50 mm

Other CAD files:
KiCAD/3d/Connectors/5031821852.stp

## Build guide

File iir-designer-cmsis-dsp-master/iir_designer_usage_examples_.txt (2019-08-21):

%///////////////////////////////////////////////////////////////
% Example 1
% 2nd order DC blocker, 20 Hz, sampling frequency = 44.1kHz
% Plots the filter response and sample signals 
%///////////////////////////////////////////////////////////////
pkg load signal
order=2
f1=20
fs=44100
plot_results=true

design_iir_highpass_cmsis_butter(order,f1,fs,plot_results);
%%%%%%%%%%%%%%%%%%%%%%%%%%%%%%%

%///////////////////////////////////////////////////////////////
% Example 2
% Elliptical bandpass between 150 and 600 Hz, 1dB ripple, 60dB
% stopband attenuation
%///////////////////////////////////////////////////////////////
pkg load signal
order=4
ripple=1
att=60
f1=150
f2=600
fs=16000
plot_results=false

design_iir_bandpass_cmsis_elliptical(order,ripple,att,f1,f2,fs,plot_results);
%%%%%%%%%%%%%%%%%%%%%%%%%%%%%%%

%///////////////////////////////////////////////////////////////
% Example 3
& Same as frequencies sd example 2, but designed as Butterworth 
% filter
%///////////////////////////////////////////////////////////////
pkg load signal
order=4
f1=150
f2=600
fs=16000
plot_results=false

design_iir_bandpass_cmsis_butter(order,f1,f2,fs,plot_results);
%%%%%%%%%%%%%%%%%%%%%%%%%%%%%%%

%///////////////////////////////////////////////////////////////
% Example 1
% 2nd order DC blocker, 20 Hz, sampling frequency = 44.1kHz
% Plots the filter response and sample signals 
%///////////////////////////////////////////////////////////////
pkg load signal
order=8
f1=55
fs=512
plot_results=true

design_iir_highpass_cmsis_butter(order,f1,fs,plot_results);
%%%%%%%%%%%%%%%%%%%%%%%%%%%%%%%

%///////////////////////////////////////////////////////////////
% Example 1
% 2nd order DC blocker, 20 Hz, sampling frequency = 44.1kHz
% Plots the filter response and sample signals 
%///////////////////////////////////////////////////////////////
pkg load signal
order=8
f1=45
fs=512
plot_results=true

design_iir_lowpass_cmsis_butter(order,f1,fs,plot_results);
%%%%%%%%%%%%%%%%%%%%%%%%%%%%%%%

%///////////////////////////////////////////////////////////////
% Example 3
& Same as frequencies sd example 2, but designed as Butterworth 
% filter
%///////////////////////////////////////////////////////////////
pkg load signal
order=8
f1=8
f2=12
fs=512
plot_results=true

design_iir_bandpass_cmsis_butter(order,f1,f2,fs,plot_results);
%%%%%%%%%%%%%%%%%%%%%%%%%%%%%%%

%///////////////////////////////////////////////////////////////
% Example 3
& Same as frequencies sd example 2, but designed as Butterworth 
% filter
%///////////////////////////////////////////////////////////////
pkg load signal
order=4
f1=8
f2=12
fs=512
plot_results=true

design_iir_bandpass_cmsis_butter(order,f1,f2,fs,plot_results);
%%%%%%%%%%%%%%%%%%%%%%%%%%%%%%%

%///////////////////////////////////////////////////////////////
% Example 3
& Same as frequencies sd example 2, but designed as Butterworth 
% filter
%///////////////////////////////////////////////////////////////
pkg load signal
order=8
f1=49
f2=51
fs=512
plot_results=true

design_iir_bandstop_cmsis_butter(order,f1,f2,fs,plot_results);
%%%%%%%%%%%%%%%%%%%%%%%%%%%%%%%

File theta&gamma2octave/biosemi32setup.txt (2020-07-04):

FP1
AF3
F7
F3
FC1
FC5
T7
C3
CP1
CP5
P7
P3
Pz
PO3
O1
Oz
O2
PO4
P4
P8
CP6
CP2
C4
T8
FC6
FC2
F4
F8
AF4
FP2
Fz
Cz
Aux1
Aux2
Aux3

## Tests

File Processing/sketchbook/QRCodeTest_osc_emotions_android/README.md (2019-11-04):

https://www.youtube.com/watch?v=jPtND5F-264

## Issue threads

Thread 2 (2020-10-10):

how to stream data from usb

INNFINITEMINDS, 2020-10-10:
Respected SIr,
as i am new to this .please guide ...

as u have provided bom and pcb files ..if i go with and bring all the componenets and print pcb ..assemble it..

than should i able to run and start freeEEg 32 ?

ho can i stream eeg data in an ubuntu pc ? ..if i connect electodes to freeEEG32 device

awaiting for reponse ,
Thanks

arpit

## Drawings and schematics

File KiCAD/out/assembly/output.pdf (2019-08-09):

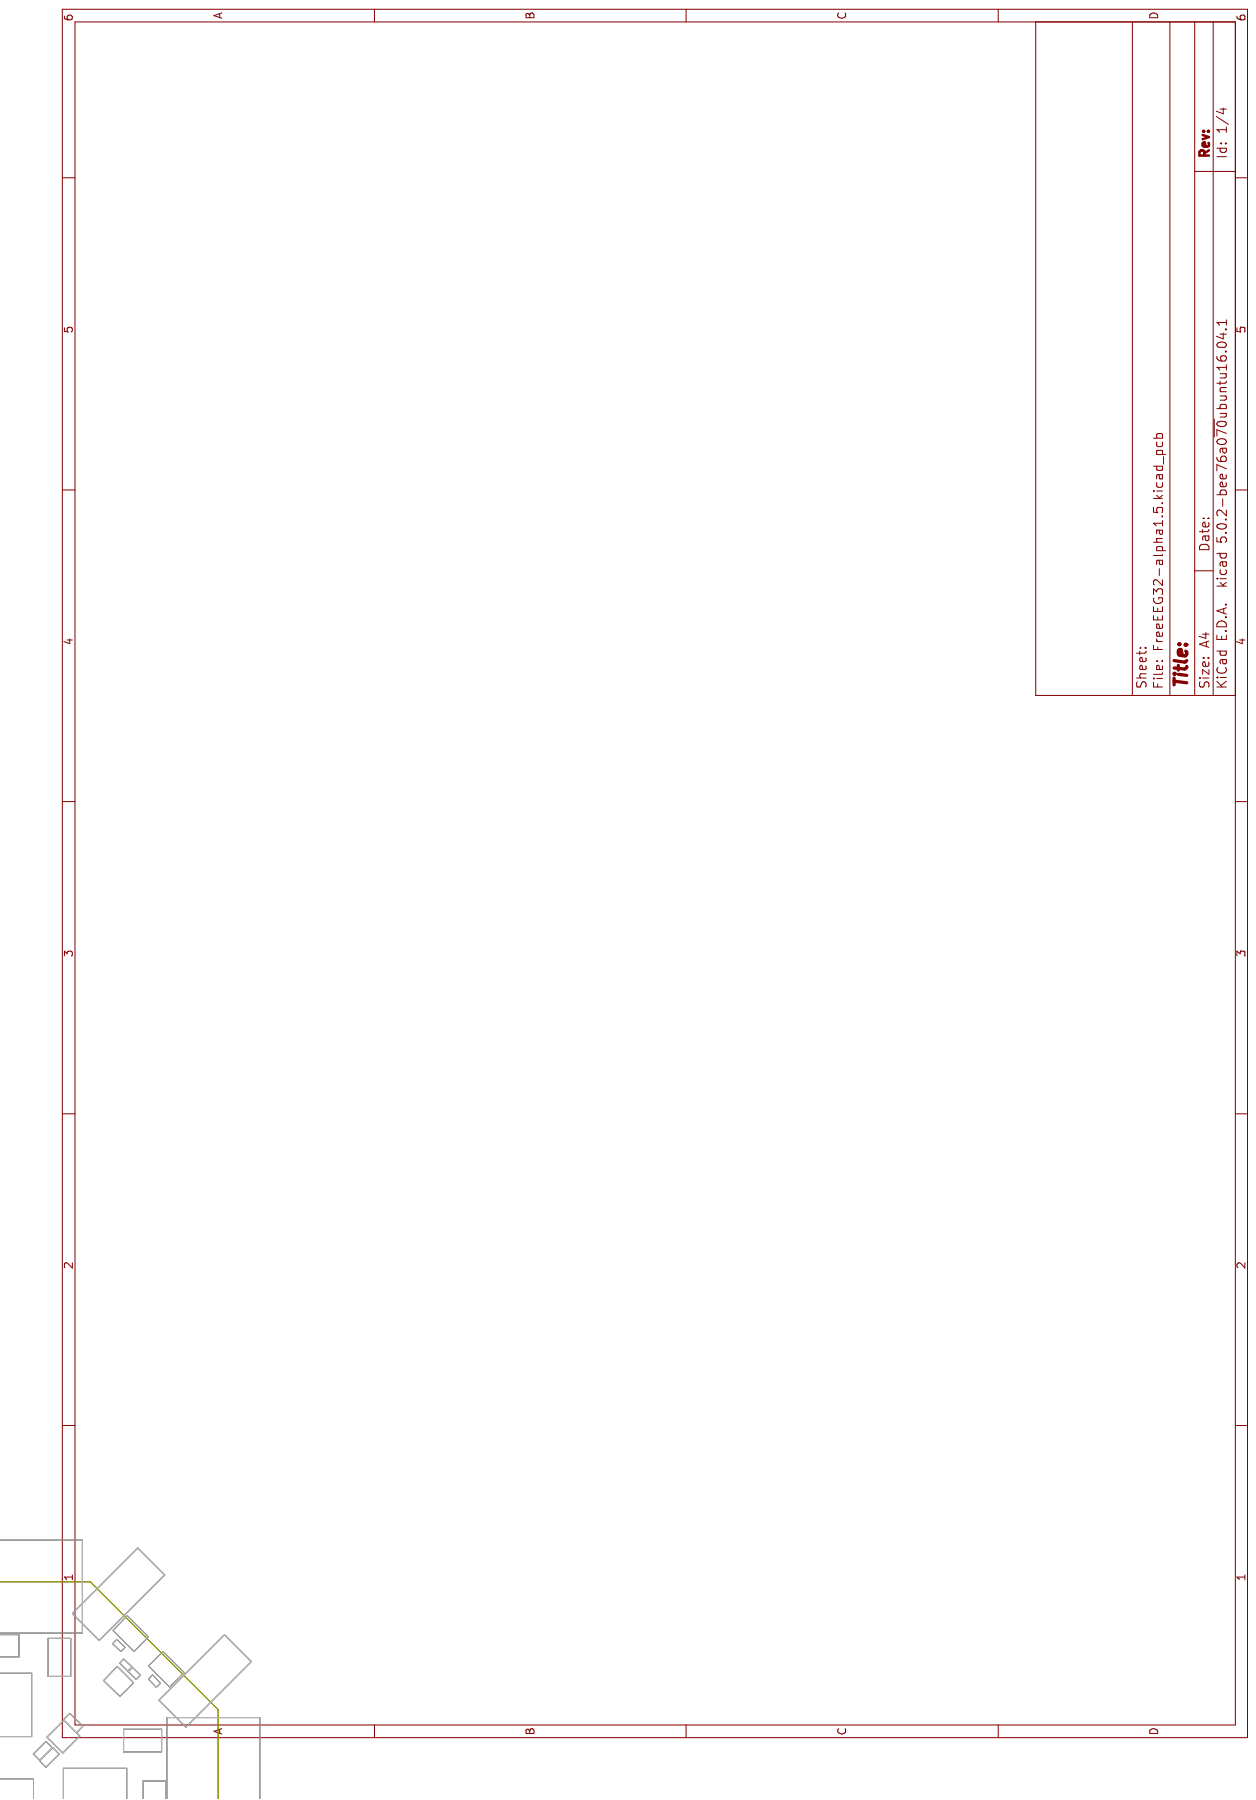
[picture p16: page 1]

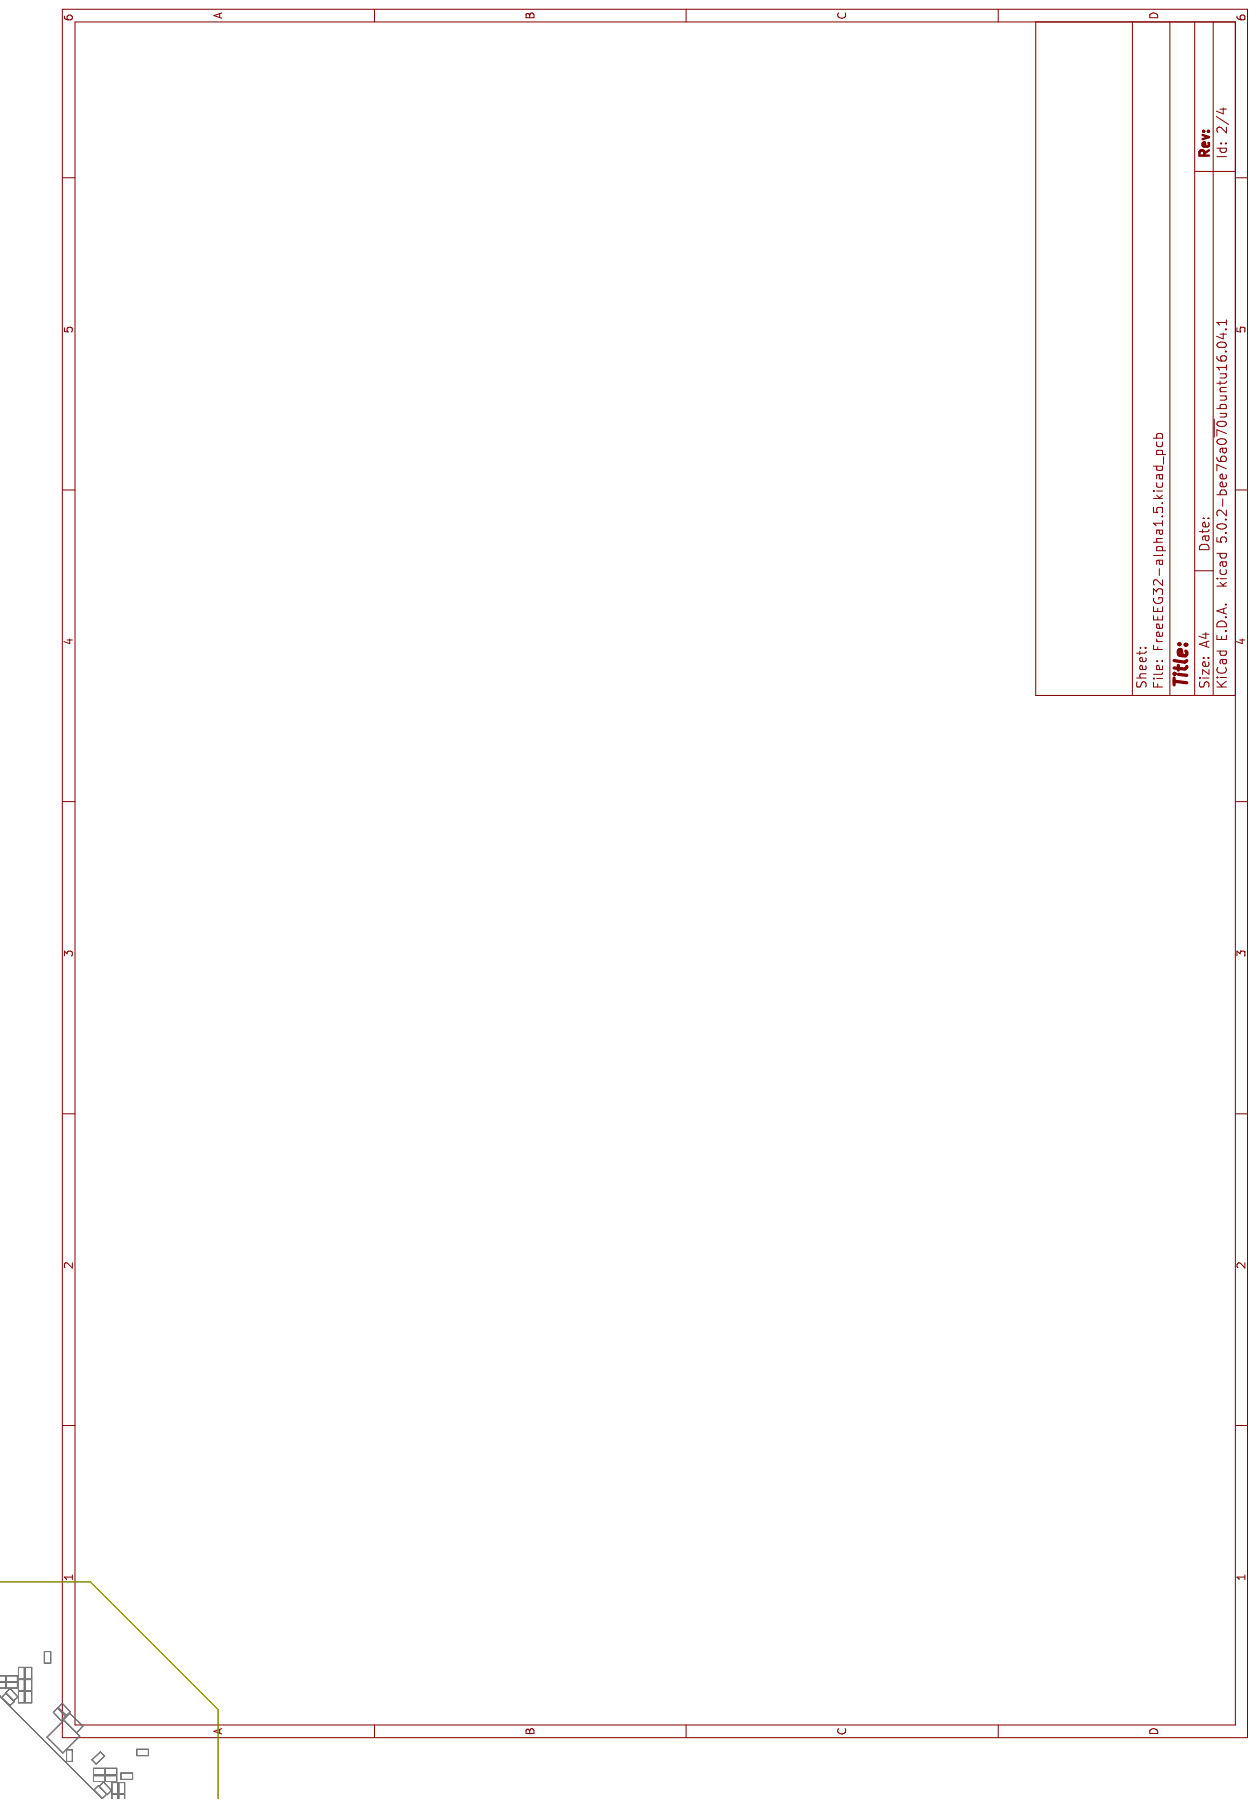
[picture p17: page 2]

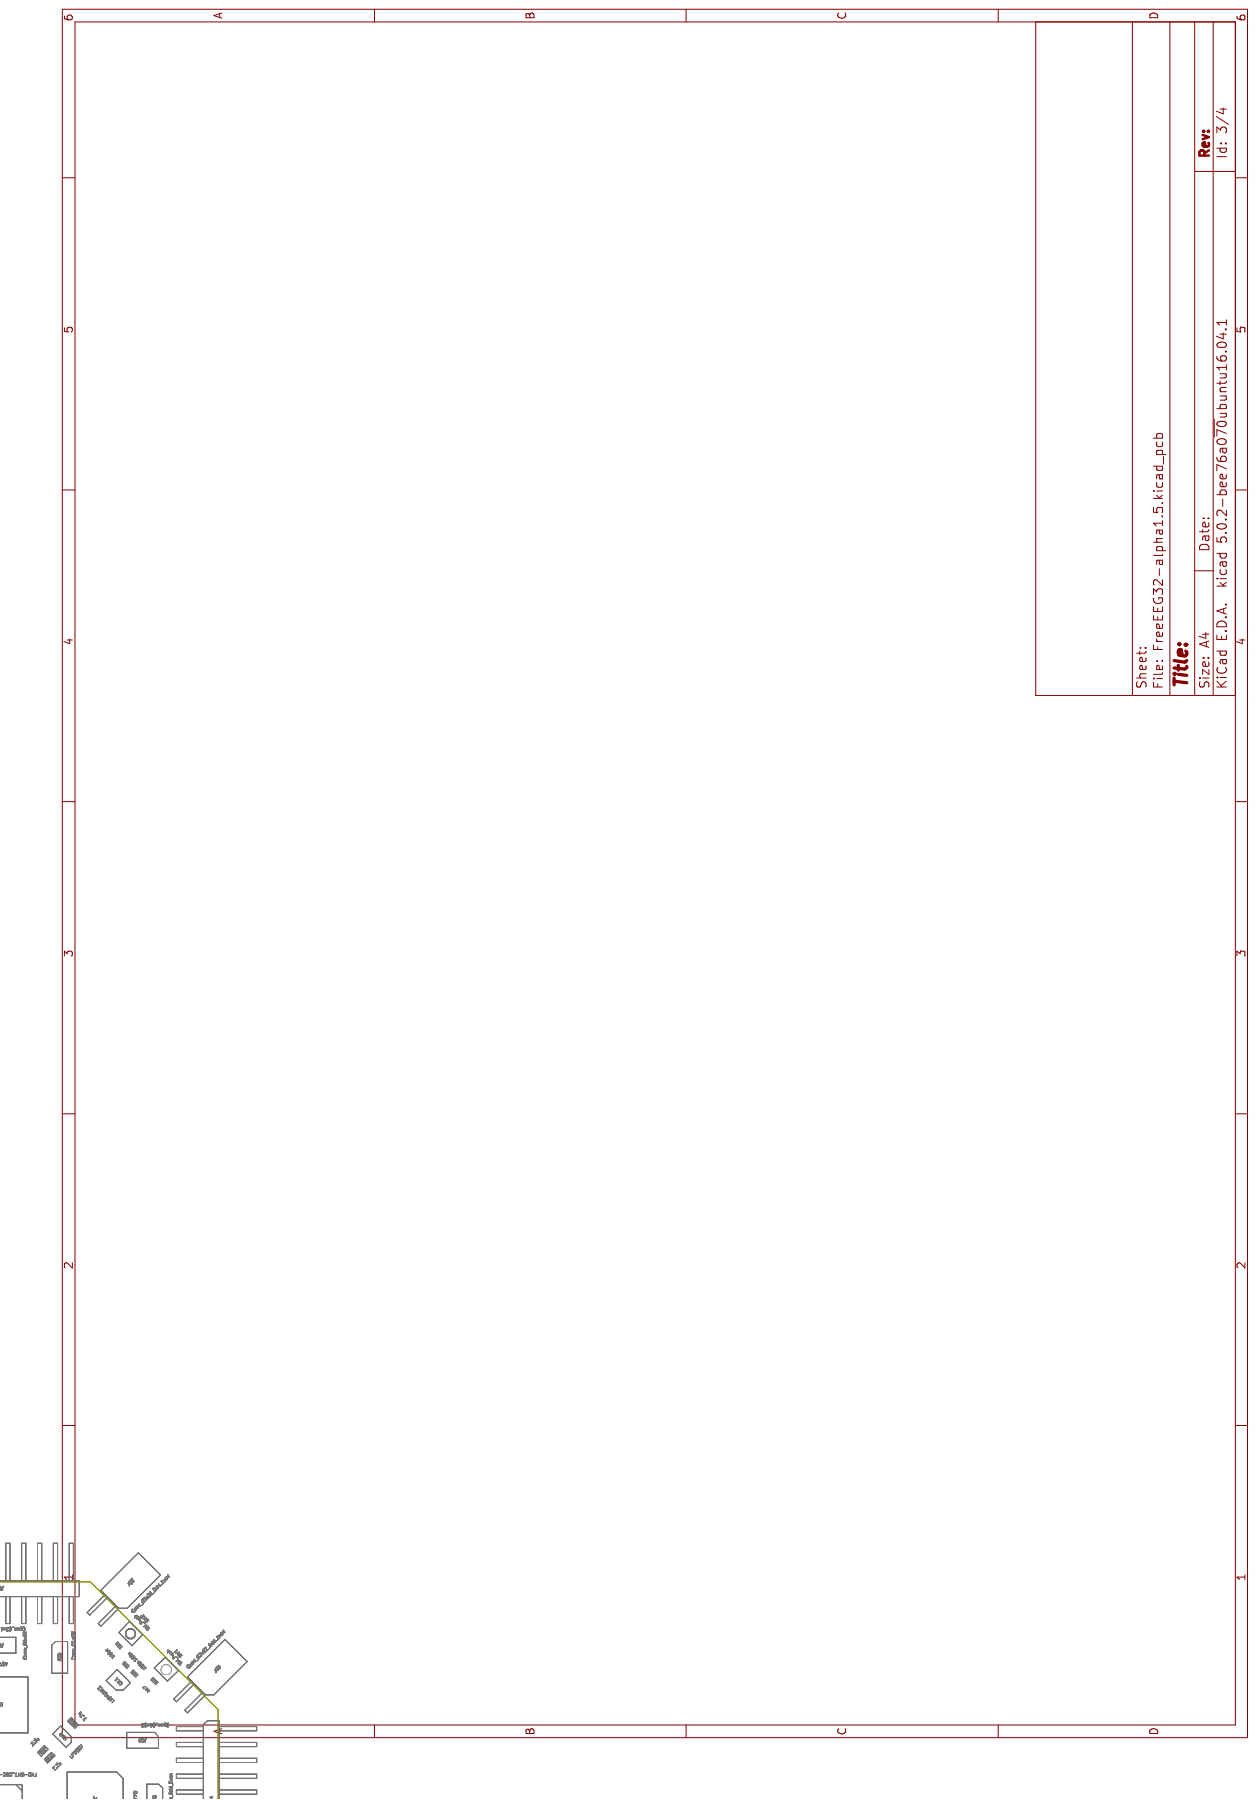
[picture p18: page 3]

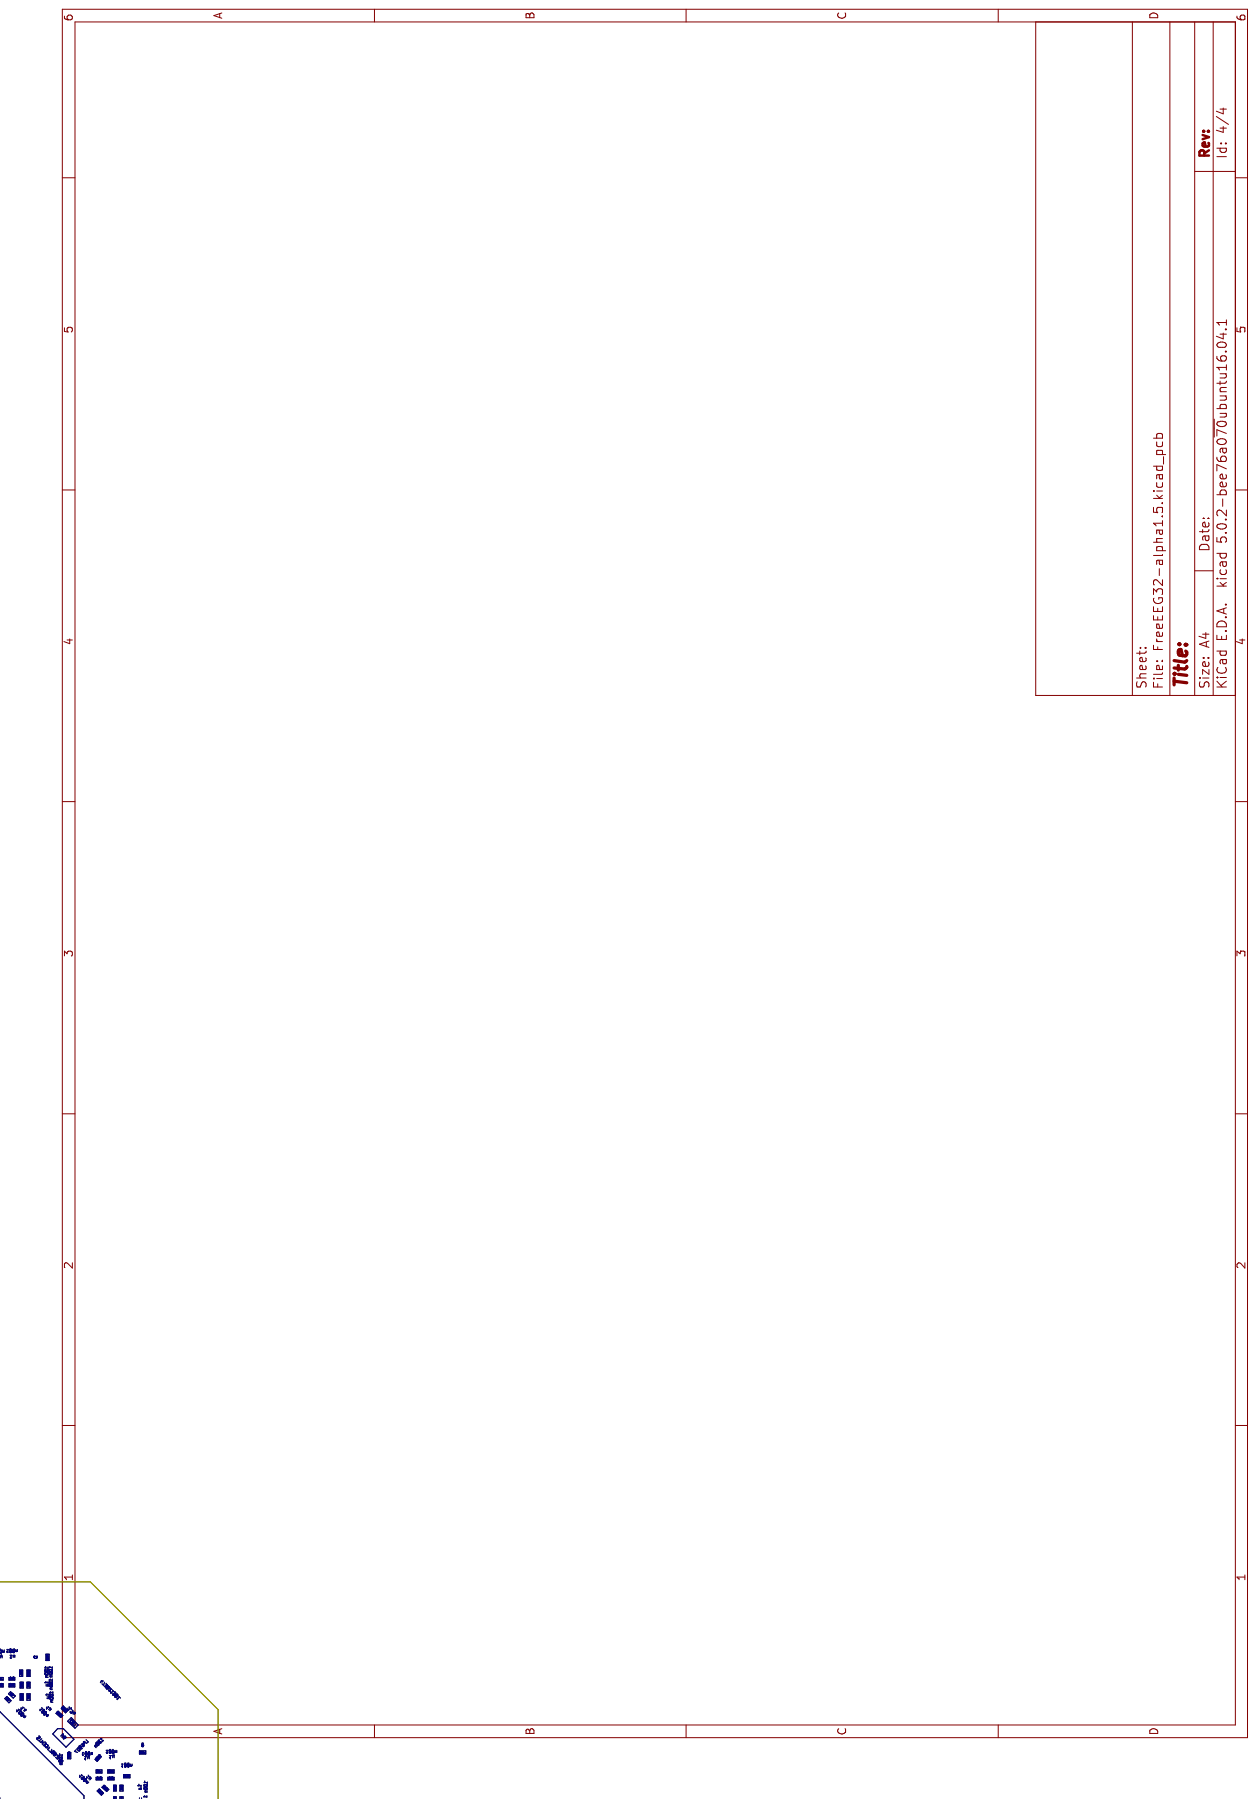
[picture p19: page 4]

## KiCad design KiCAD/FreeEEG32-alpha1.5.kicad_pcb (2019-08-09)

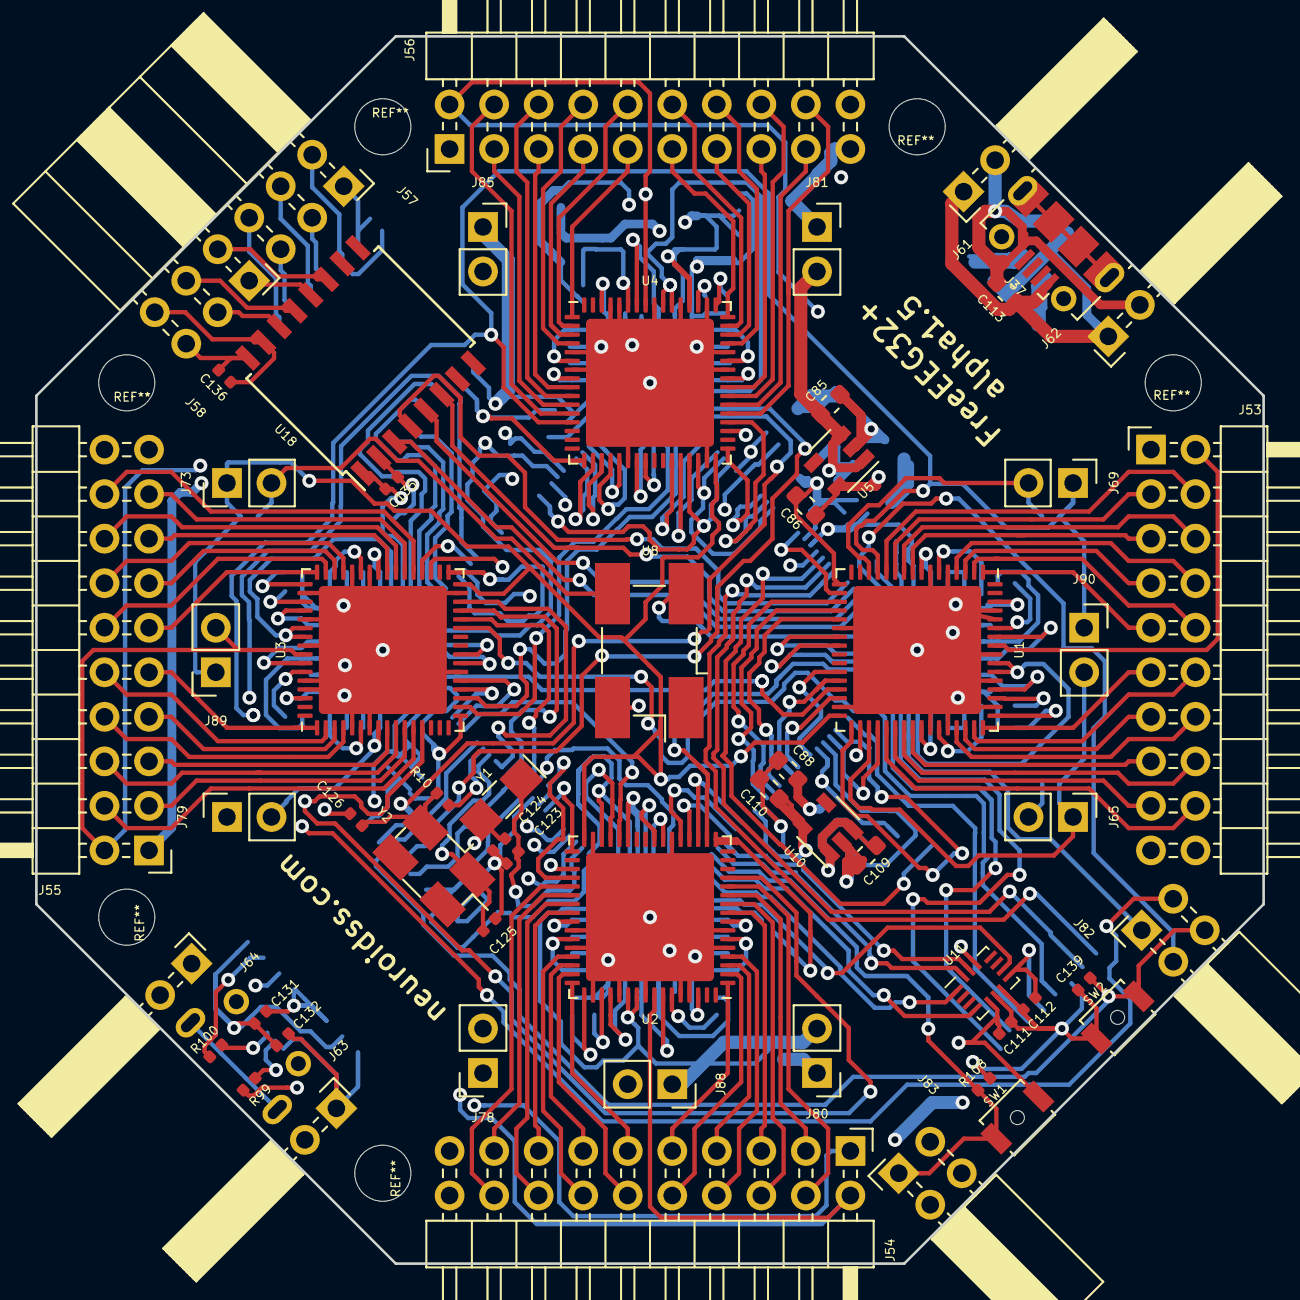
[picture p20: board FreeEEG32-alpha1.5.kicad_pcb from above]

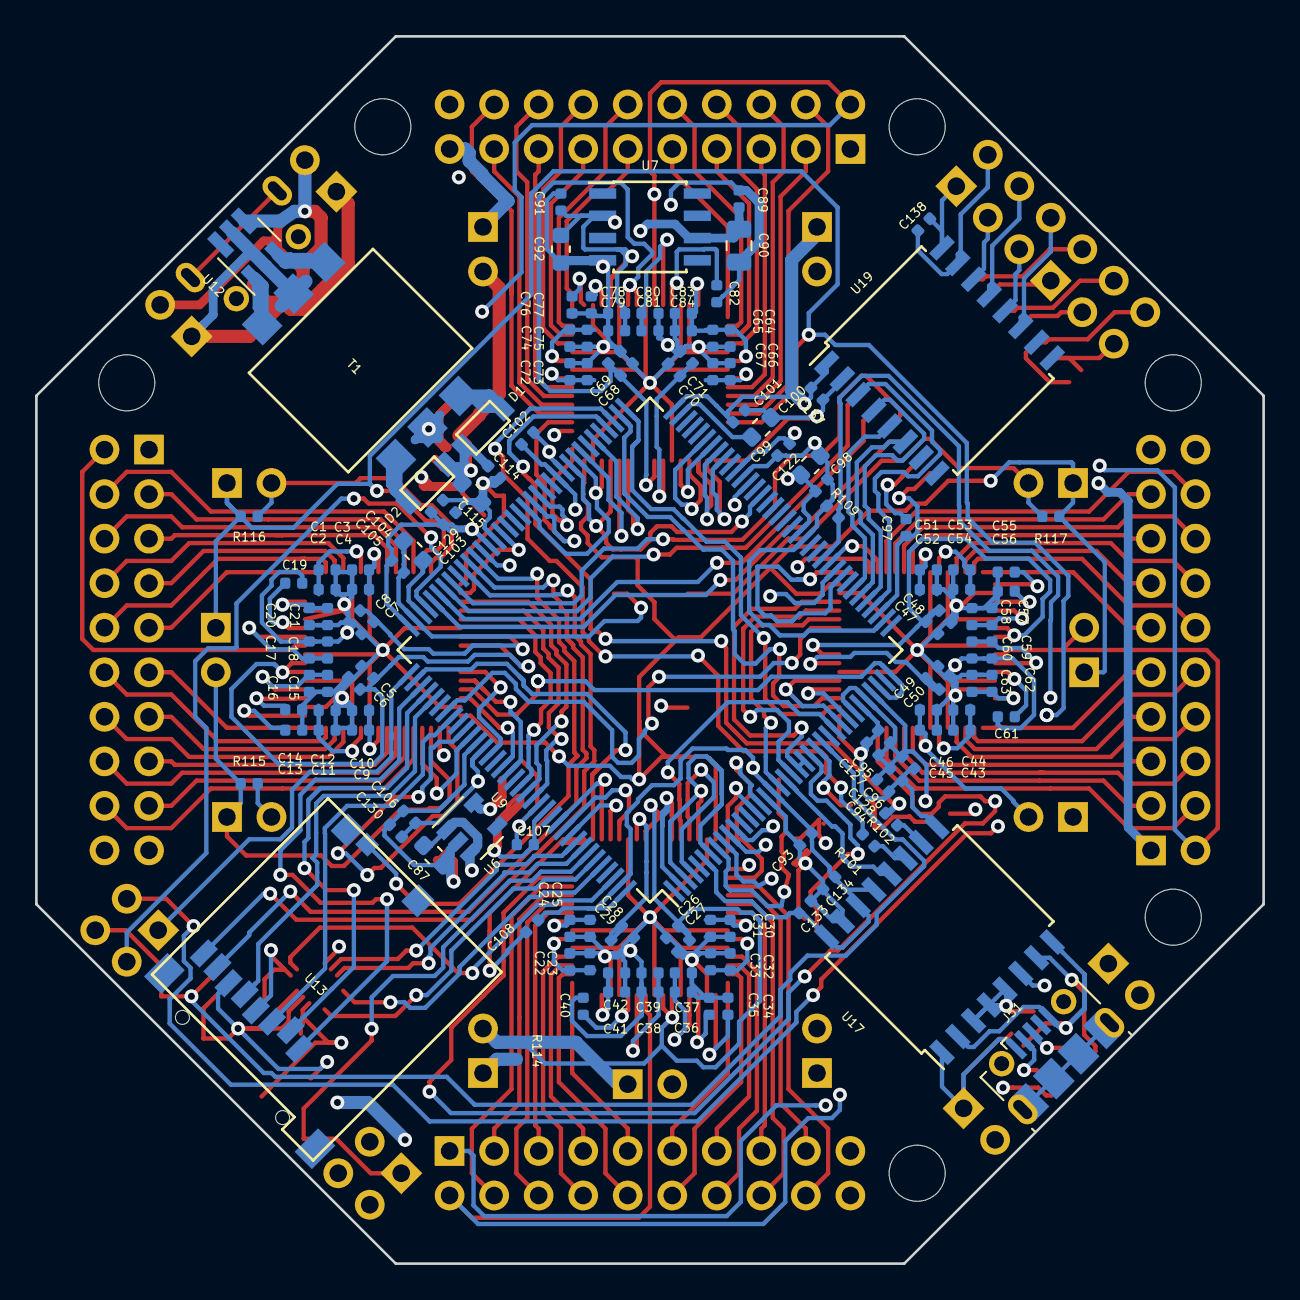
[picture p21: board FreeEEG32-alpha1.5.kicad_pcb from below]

Board: 4 copper layers, 70.0 x 70.0 mm, 192 parts (134 on the bottom side), 199 nets.

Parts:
C1, C3, C5, C7, C9, C11, C13, C14, C15, C17, C19, C20, C22, C24, C26, C28, C30, C32, C34, C35, C36, C38, C40, C41, C43, C45, C47, C49, C51, C53, C55, C56, C57, C59, C61, C62, C64, C66, C68, C70, C72, C74, C76, C77, C78, C80, C82, C83, C89, C91, C93, C94, C95, C96, C97, C98, C99, C101, C102, C103, C105, C106, C107, C108, C111, C112, C114, C131, C132, C133, C134, C135, C136, C137, C138, C139: 100n; C_0402_1005Metric
C2, C4, C6, C8, C10, C12, C16, C18, C21, C23, C25, C27, C29, C31, C33, C37, C39, C42, C44, C46, C48, C50, C52, C54, C58, C60, C63, C65, C67, C69, C71, C73, C75, C79, C81, C84, C127, C128, C129, C130: 1u; C_0402_1005Metric
C85, C86, C87, C88, C100, C104, C109, C110: 2.2u; C_0603_1608Metric
C90: 22u; C_0805_2012Metric
C92, C113, C115: 10u; C_0603_1608Metric
C122: 4.7u; C_0603_1608Metric
C123, C125: CL1; C_0402_1005Metric
C124, C126: CL2; C_0402_1005Metric
D1, D2: D_Schottky; SOD−123
J37, J51: USB_B_Micro; USB_Micro-B_Molex-105017-0001
J53, J54, J55, J56: Conn_02x10_Odd_Even; PinHeader_2x10_P2.54mm_Horizontal
J57, J58: Conn_02x03_Odd_Even; PinSocket_2x03_P2.54mm_Horizontal
J61, J62, J63, J64: Conn_01x02; PinSocket_2x01_P2.54mm_Horizontal
J65, J69, J73, J80: Conn_01x02; PinHeader_1x02_P2.54mm_Vertical
J78, J79, J81, J85, J88, J89, J90: Conn_01x02; PinSocket_1x02_P2.54mm_Vertical
J82, J83: Conn_02x02_Odd_Even; PinSocket_2x02_P2.54mm_Horizontal
R10: R_EXT; R_0402_1005Metric
R99, R100, R101, R102: 20; R_0402_1005Metric
R108, R109: 4k7; R_0402_1005Metric
R114, R115, R116, R117: 0; R_0402_1005Metric
SW1, SW2: SW_Push; SW_SPST_B3U-1000P-B
T1: da2303; 750315371
U1, U2, U3, U4: AD7779; QFN-64-1EP_9x9mm_P0.5mm_EP7.3x7.3mm
U5, U6, U10: LP5907; SOT-23-5
U7: ADR4525; SOIC-8_3.9x4.9mm_P1.27mm
U8: FXO-SM7_OSC-SMD7050_short; Oscillator_SMD_EuroQuartz_XO91-4Pin_7.0x5.0mm_HandSoldering
U9: STM32F765ZITx; LQFP-144_20x20mm_P0.5mm
U11: LSM6DS3; Bosch_LGA-14_3x2.5mm_P0.5mm
U12: SN6505A; SOT-23-6_Handsoldering
U13: 473521001
U17: ADuM3160; SOIC-16W_7.5x10.3mm_P1.27mm
U18: ADUM1402BRWZ; SOIC-16W_7.5x10.3mm_P1.27mm
U19: ISO7341c; SOIC-16W_7.5x10.3mm_P1.27mm
Y1: 32768Hz; Crystal_SMD_EuroQuartz_EQ161-2Pin_3.2x1.5mm_HandSoldering
Y2: 16MHz; Crystal_SMD_EuroQuartz_MJ-4Pin_5.0x3.2mm_HandSoldering

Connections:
/ADC1/1_AIN0-: J53.9, U1.1
/ADC1/2_AIN0+: J53.10, U1.2
/ADC1/3_AIN1-: J53.7, U1.3
/ADC1/4_AIN1+: J53.8, U1.4
/ADC1/9_AIN2-: J53.5, U1.9
/ADC1/10_AIN2+: J53.6, U1.10
/ADC1/11_AIN3-: J53.3, U1.11
/ADC1/12_AIN3+: J53.4, U1.12
/ADC1/37_AIN7+: J53.18, U1.37
/ADC1/38_AIN7-: J53.17, U1.38
/ADC1/39_AIN6+: J53.16, U1.39
/ADC1/40_AIN6-: J53.15, U1.40
/ADC1/45_AIN5+: J53.14, U1.45
/ADC1/46_AIN5-: J53.13, U1.46
/ADC1/47_AIN4+: J53.12, U1.47
/ADC1/48_AIN4-: J53.11, U1.48
/ADC1/49_REF_OUT: C13.1, U1.49
/ADC1/51_AREG2CAP: C14.1, U1.51
/ADC1/59_AREG1CAP: C19.1, U1.59
/ADC2/1_AIN0-: J54.9, U2.1
/ADC2/2_AIN0+: J54.10, U2.2
/ADC2/3_AIN1-: J54.7, U2.3
/ADC2/4_AIN1+: J54.8, U2.4
/ADC2/9_AIN2-: J54.5, U2.9
/ADC2/10_AIN2+: J54.6, U2.10
/ADC2/11_AIN3-: J54.3, U2.11
/ADC2/12_AIN3+: J54.4, U2.12
/ADC2/37_AIN7+: J54.18, U2.37
/ADC2/38_AIN7-: J54.17, U2.38
/ADC2/39_AIN6+: J54.16, U2.39
/ADC2/40_AIN6-: J54.15, U2.40
/ADC2/45_AIN5+: J54.14, U2.45
/ADC2/46_AIN5-: J54.13, U2.46
/ADC2/47_AIN4+: J54.12, U2.47
/ADC2/48_AIN4-: J54.11, U2.48
/ADC2/49_REF_OUT: C34.1, U2.49
/ADC2/51_AREG2CAP: C35.1, U2.51
/ADC2/59_AREG1CAP: C40.1, U2.59
/ADC3/1_AIN0-: J55.9, U3.1
/ADC3/2_AIN0+: J55.10, U3.2
/ADC3/3_AIN1-: J55.7, U3.3
/ADC3/4_AIN1+: J55.8, U3.4
/ADC3/9_AIN2-: J55.5, U3.9
/ADC3/10_AIN2+: J55.6, U3.10
/ADC3/11_AIN3-: J55.3, U3.11
/ADC3/12_AIN3+: J55.4, U3.12
/ADC3/37_AIN7+: J55.18, U3.37
/ADC3/38_AIN7-: J55.17, U3.38
/ADC3/39_AIN6+: J55.16, U3.39
/ADC3/40_AIN6-: J55.15, U3.40
/ADC3/45_AIN5+: J55.14, U3.45
/ADC3/46_AIN5-: J55.13, U3.46
/ADC3/47_AIN4+: J55.12, U3.47
/ADC3/48_AIN4-: J55.11, U3.48
/ADC3/49_REF_OUT: C55.1, U3.49
/ADC3/51_AREG2CAP: C56.1, U3.51
/ADC3/59_AREG1CAP: C61.1, U3.59
/ADC4/37_AIN7+: J56.18, U4.37
/ADC4/38_AIN7-: J56.17, U4.38
/ADC4/39_AIN6+: J56.16, U4.39
/ADC4/40_AIN6-: J56.15, U4.40
/ADC4/45_AIN5+: J56.14, U4.45
/ADC4/46_AIN5-: J56.13, U4.46
/ADC4/47_AIN4+: J56.12, U4.47
/ADC4/48_AIN4-: J56.11, U4.48
/ADC4/49_REF_OUT: C76.1, U4.49
/ADC4/51_AREG2CAP: C77.1, U4.51
/ADC4/59_AREG1CAP: C82.1, U4.59
/MCU/8_PC14: C123.1, U9.8, Y1.1
/MCU/9_PC15: C124.1, U9.9, Y1.2
/MCU/23_PH0: C125.1, U9.23, Y2.1
/MCU/24_PH1: R10.1, U9.24
/MCU/71_VCAP_1: C100.1, U9.71
/MCU/106_VCAP_2: C104.1, U9.106
ACC_1_SDO_SAO: U9.140, U11.1
ACC_4_INT1: U9.139, U11.4
ACC_6_GND: C1.1, C2.1, C3.1, C4.1, C5.1, C6.1, C7.1, C8.1, C9.1, C10.1, C11.1, C12.1, C13.2, C14.2, C15.1, C16.1, C17.1, C18.1, C19.2, C20.2, C21.2, C22.1, C23.1, C24.1, C25.1, C26.1, C27.1, C28.1, C29.1, C30.1, C31.1, C32.1, C33.1, C34.2, C35.2, C36.1, C37.1, C38.1, C39.1, C40.2, C41.2, C42.2, C43.1, C44.1, C45.1, C46.1, C47.1, C48.1, C49.1, C50.1, C51.1, C52.1, C53.1, C54.1, C55.2, C56.2, C57.1, C58.1, C59.1, C60.1, C61.2, C62.2, C63.2, C64.1, C65.1, C66.1, C67.1, C68.1, C69.1, C70.1, C71.1, C72.1, C73.1, C74.1, C75.1, C76.2, C77.2, C78.1, C79.1, C80.1, C81.1, C82.2, C83.2, C84.2, C85.2, C86.2, C87.2, C88.2, C89.2, C90.2, C91.2, C92.2, C93.2, C94.2, C95.2, C96.2, C97.2, C98.2, C99.2, C100.2, C101.2, C102.2, C103.2, C104.2, C105.2, C106.2, C107.2, C108.2, C109.2, C110.2, C111.2, C112.2, C114.2, C115.2, C122.2, C123.2, C124.2, C125.2, C126.2, C127.2, C128.2, C129.2, C130.2, C133.2, C134.2, C135.2, C137.2, C139.1, J53.19, J54.19, J55.19, J56.19, J79.1, J81.1, J83.4, R108.2, R109.2, SW2.1, T1.7, U1.5, U1.7, U1.17, U1.22, U1.31, U1.42, U1.44, U1.50, U1.53, U1.56, U1.60, U1.61, U1.65, U2.5, U2.7, U2.17, U2.22, U2.31, U2.42, U2.44, U2.50, U2.53, U2.56, U2.60, U2.61, U2.65, U3.5, U3.7, U3.17, U3.22, U3.31, U3.42, U3.44, U3.50, U3.53, U3.56, U3.60, U3.61, U3.65, U4.5, U4.7, U4.17, U4.22, U4.31, U4.42, U4.44, U4.50, U4.53, U4.56, U4.60, U4.61, U4.65, U5.2, U6.2, U7.4, U8.2, U9.16, U9.31, U9.38, U9.51, U9.61, U9.83, U9.94, U9.107, U9.120, U9.130, U10.2, U11.6, U11.7, U13.6, U17.9, U17.15, U18.2, U19.2
ACC_9_INT2: U9.142, U11.9
ACC_12_CS: C93.1, C94.1, C95.1, C96.1, C97.1, C98.1, C99.1, C101.1, C102.1, C103.1, C105.1, C106.1, C107.1, C108.1, C110.1, C111.1, C112.1, C122.1, C127.1, C128.1, C129.1, C130.1, C133.1, C134.1, C135.1, C137.1, J83.3, J85.1, SW1.1, U9.6, U9.17, U9.30, U9.32, U9.33, U9.39, U9.52, U9.62, U9.72, U9.84, U9.95, U9.108, U9.121, U9.131, U9.143, U9.144, U10.5, U11.5, U11.8, U11.12, U13.4, U17.13, U17.14, U17.16, U18.1, U19.1
ACC_13_SCL: U9.136, U11.13
ACC_14_SDA: U9.137, U11.14
ADC1_13_MODE0_GPIO0: J69.1, J90.1, R116.2, U1.13, U2.13, U3.13, U4.13
ADC1_14_MODE1_GPIO1: J69.2, R116.1, U1.14
ADC1_18_ALERT_CS: U1.18, U9.93
ADC1_19_DCLK2_SCLK: U1.19, U9.128
ADC1_20_DCLK1_SDI: U1.20, U9.129
ADC1_21_DCLK0_SDO: U1.21, U9.127
ADC1_23_DREGCAP: C7.2, C8.2, U1.23
ADC1_24_IOVDD: C5.2, C6.2, C26.2, C27.2, C47.2, C48.2, C68.2, C69.2, C88.1, J80.2, J88.1, R114.1, U1.24, U1.54, U1.55, U2.24, U2.54, U2.55, U3.24, U3.54, U3.55, U4.24, U4.54, U4.55, U6.5
ADC1_27_DOUT1: U1.27, U9.122
ADC1_28_DOUT0: U1.28, U9.125
ADC1_29_DCLK: U1.29, U9.34, U9.36
ADC1_30_DRDY: U1.30, U9.46, U9.96, U9.124
ADC1_32_XTAL2_MCLK: J73.1, J89.1, R117.2, U1.32, U2.32, U3.32, U4.32
ADC1_33_START: U1.33, U9.118
ADC1_34_SYNC_OUT: J65.2, R115.1, U1.34
ADC1_35_SYNC_IN: J65.1, J90.2, R115.2, U1.35, U2.35, U3.35, U4.35
ADC1_36_RESET: U1.36, U9.119
ADC1_41_REF2+: C3.2, C4.2, C9.2, C10.2, C24.2, C25.2, C30.2, C31.2, C45.2, C46.2, C51.2, C52.2, C66.2, C67.2, C72.2, C73.2, C89.1, C90.1, J79.2, U1.8, U1.41, U2.8, U2.41, U3.8, U3.41, U4.8, U4.41, U7.6
ADC1_43_AVDD1B: C1.2, C2.2, C11.2, C12.2, C15.2, C16.2, C17.2, C18.2, C20.1, C21.1, C22.2, C23.2, C32.2, C33.2, C36.2, C37.2, C38.2, C39.2, C41.1, C42.1, C43.2, C44.2, C53.2, C54.2, C57.2, C58.2, C59.2, C60.2, C62.1, C63.1, C64.2, C65.2, C74.2, C75.2, C78.2, C79.2, C80.2, C81.2, C83.1, C84.1, C86.1, C91.1, C92.1, J53.20, J54.20, J55.20, J56.20, J85.2, U1.6, U1.43, U1.52, U1.58, U1.62, U2.6, U2.43, U2.52, U2.58, U2.62, U3.6, U3.43, U3.52, U3.58, U3.62, U4.6, U4.43, U4.52, U4.58, U4.62, U5.5, U7.2
ADC1_57_VCM: J53.2, J54.2, J55.2, J56.2, J89.2, U1.57, U2.57, U3.57, U4.57
ADC2_18_ALERT_CS: U2.18, U9.110
ADC2_19_DCLK2_SCLK: U2.19, U9.133
ADC2_20_DCLK1_SDI: U2.20, U9.135
ADC2_21_DCLK0_SDO: U2.21, U9.134
ADC2_23_DREGCAP: C28.2, C29.2, U2.23
ADC2_27_DOUT1: U2.27, U9.2
ADC2_28_DOUT0: U2.28, U9.27
ADC2_29_DCLK: U2.29, U9.4
ADC2_30_DRDY: U2.30, U9.3, U9.7
ADC2_33_START: U2.33, U9.14
ADC2_36_RESET: U2.36, U9.15
ADC3_18_ALERT_CS: U3.18, U9.73
ADC3_19_DCLK2_SCLK: U3.19, U9.74
ADC3_20_DCLK1_SDI: U3.20, U9.29
ADC3_21_DCLK0_SDO: U3.21, U9.28
ADC3_23_DREGCAP: C49.2, C50.2, U3.23
ADC3_27_DOUT1: U3.27, U9.115
ADC3_28_DOUT0: U3.28, U9.18
ADC3_29_DCLK: U3.29, U9.20
ADC3_30_DRDY: U3.30, U9.21, U9.22
ADC3_33_START: U3.33, U9.45
ADC3_36_RESET: U3.36, U9.47
ADC4_18_ALERT_CS: U4.18, U9.64
ADC4_19_DCLK2_SCLK: U4.19, U9.65
ADC4_20_DCLK1_SDI: U4.20, U9.67
ADC4_21_DCLK0_SDO: U4.21, U9.66
ADC4_23_DREGCAP: C70.2, C71.2, U4.23
ADC4_27_DOUT1: U4.27, U9.78
ADC4_28_DOUT0: U4.28, U9.80
ADC4_29_DCLK: U4.29, U9.58, U9.82
ADC4_30_DRDY: U4.30, U9.60, U9.81, U9.89
ADC4_33_START: U4.33, U9.87
ADC4_36_RESET: U4.36, U9.88
ADC4_AIN0+: J56.10, U4.2
ADC4_AIN0-: J56.9, U4.1
ADC4_AIN1+: J56.8, U4.4
ADC4_AIN1-: J56.7, U4.3
ADC4_AIN2+: J56.6, U4.10
ADC4_AIN2-: J56.5, U4.9
ADC4_AIN3+: J56.4, U4.12
ADC4_AIN3-: J56.3, U4.11
AINREF-: J53.1, J54.1, J55.1, J56.1, J88.2
AVDD_1_IN: C85.1, C87.1, C109.1, C114.1, C115.1, D1.1, D2.1, J81.2, J83.2, U5.1, U5.3, U6.1, U6.3, U10.1, U10.3
CRYSTAL_3_OUT: J73.2, R117.1, U8.3
CRYSTAL_4_Vin: J80.1, R114.2, U8.4
ISO_SPI_3_INA: U9.40, U19.3
ISO_SPI_4_INB: U9.41, U19.4
ISO_SPI_5_INC: U9.43, U19.5
ISO_SPI_6_OUTD: U9.42, U19.6
ISO_SPI_11_IND: J57.6, U19.11
ISO_SPI_12_OUTC: J57.5, U19.12
ISO_SPI_13_OUTB: J57.4, U19.13
ISO_SPI_14_OUTA: J57.3, U19.14
ISO_SPI_15_GND2: C138.2, J57.2, U19.15
ISO_SPI_16_VCC2: C138.1, J57.1, U19.16
ISO_UART_3_INA: U9.104, U18.3
ISO_UART_4_INB: U9.101, U18.4
ISO_UART_5_OUTC: U9.103, U18.5
ISO_UART_6_OUTD: U9.102, U18.6
ISO_UART_11_IND: J58.2, U18.11
ISO_UART_12_INC: J58.1, U18.12
ISO_UART_13_OUTB: J58.4, U18.13
ISO_UART_14_OUTA: J58.3, U18.14
ISO_UART_15_GND2: C136.2, J58.6, U18.15
ISO_UART_16_VCC2: C136.1, J58.5, U18.16
ISO_USB_1_VBUS1: C132.1, J51.1, J63.1, U17.1
ISO_USB_2_GND1: C131.2, C132.2, J51.5, J63.2, U17.2, U17.8
ISO_USB_3_VDD1: C131.1, U17.3, U17.4, U17.5
ISO_USB_6_UD–: J51.2, J64.2, R99.2
ISO_USB_7_UD+: J51.3, J64.1, R100.2
ISO_USB_10_DD+: R102.1, U9.76
ISO_USB_11_DD–: R101.1, U9.75
ISO_USB_12_PIN: U9.19, U17.12
MCU_10_PF0_I2C2_SDA: J78.2, U9.10
MCU_11_PF1_I2C2_SCL: J78.1, U9.11
MCU_25_NRST: C139.2, J82.4, SW2.2, U9.25
MCU_48_PB2_BOOT1: J82.3, R109.1, U9.48
MCU_97_PC7_SDMMC1_DETECT: U9.97, U13.9
MCU_98_PC8_SDMMC1_D0: U9.98, U13.7
MCU_99_PC9_SDMMC1_D1: U9.99, U13.8
MCU_105_PA13_SYS_JTMS-SWDIO: J82.2, U9.105
MCU_109_PA14_SYS_JTCK-SWCLK: J82.1, U9.109
MCU_111_PC10_SDMMC1_D2: U9.111, U13.1
MCU_112_PC11_SDMMC1_D3: U9.112, U13.2
MCU_113_PC12_SDMMC1_CK: U9.113, U13.5
MCU_116_PD2_SDMMC1_CMD: U9.116, U13.3
MCU_138_BOOT0: J83.1, R108.1, SW1.2, U9.138
unnamed: C126.1, R10.2, Y2.2
unnamed: D1.2, T1.8
unnamed: D2.2, T1.5
unnamed: R99.1, U17.6
unnamed: R100.1, U17.7
unnamed: R101.2, U17.11
unnamed: R102.2, U17.10
unnamed: T1.1, U12.3
unnamed: T1.4, U12.1
POWER_1_GND: C113.1, J37.5, J61.2, J62.2, U12.4
POWER_2_VCC: C113.2, J37.1, J61.1, J62.1, T1.2, U12.2, U12.5

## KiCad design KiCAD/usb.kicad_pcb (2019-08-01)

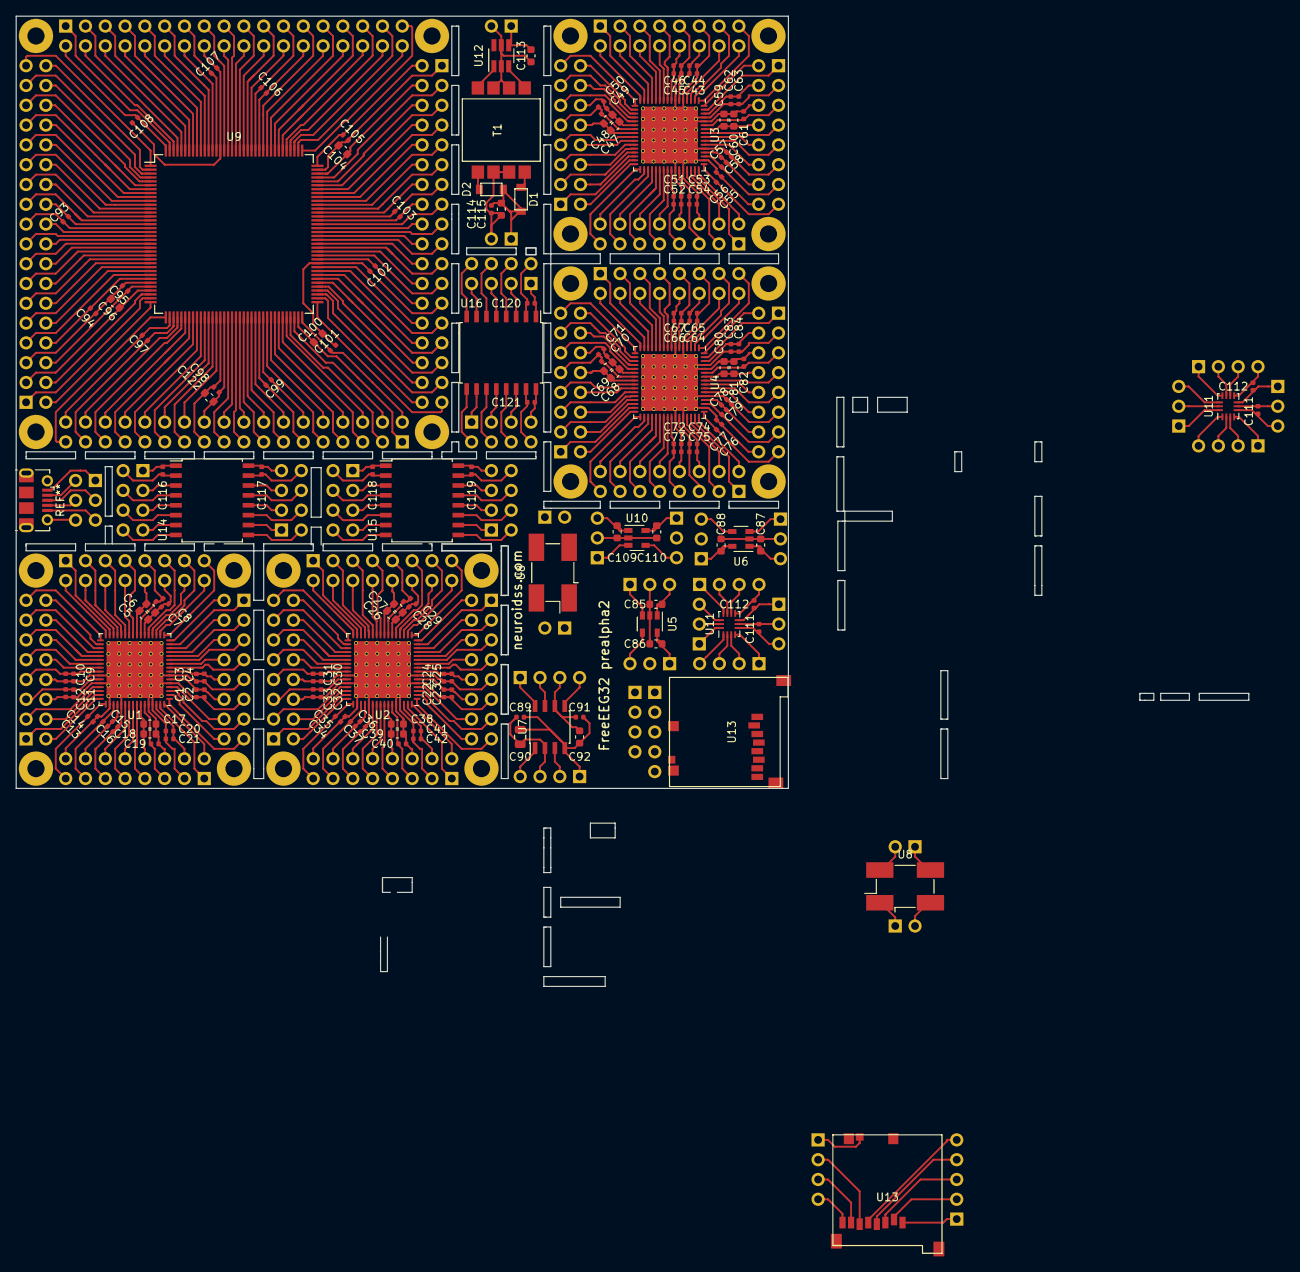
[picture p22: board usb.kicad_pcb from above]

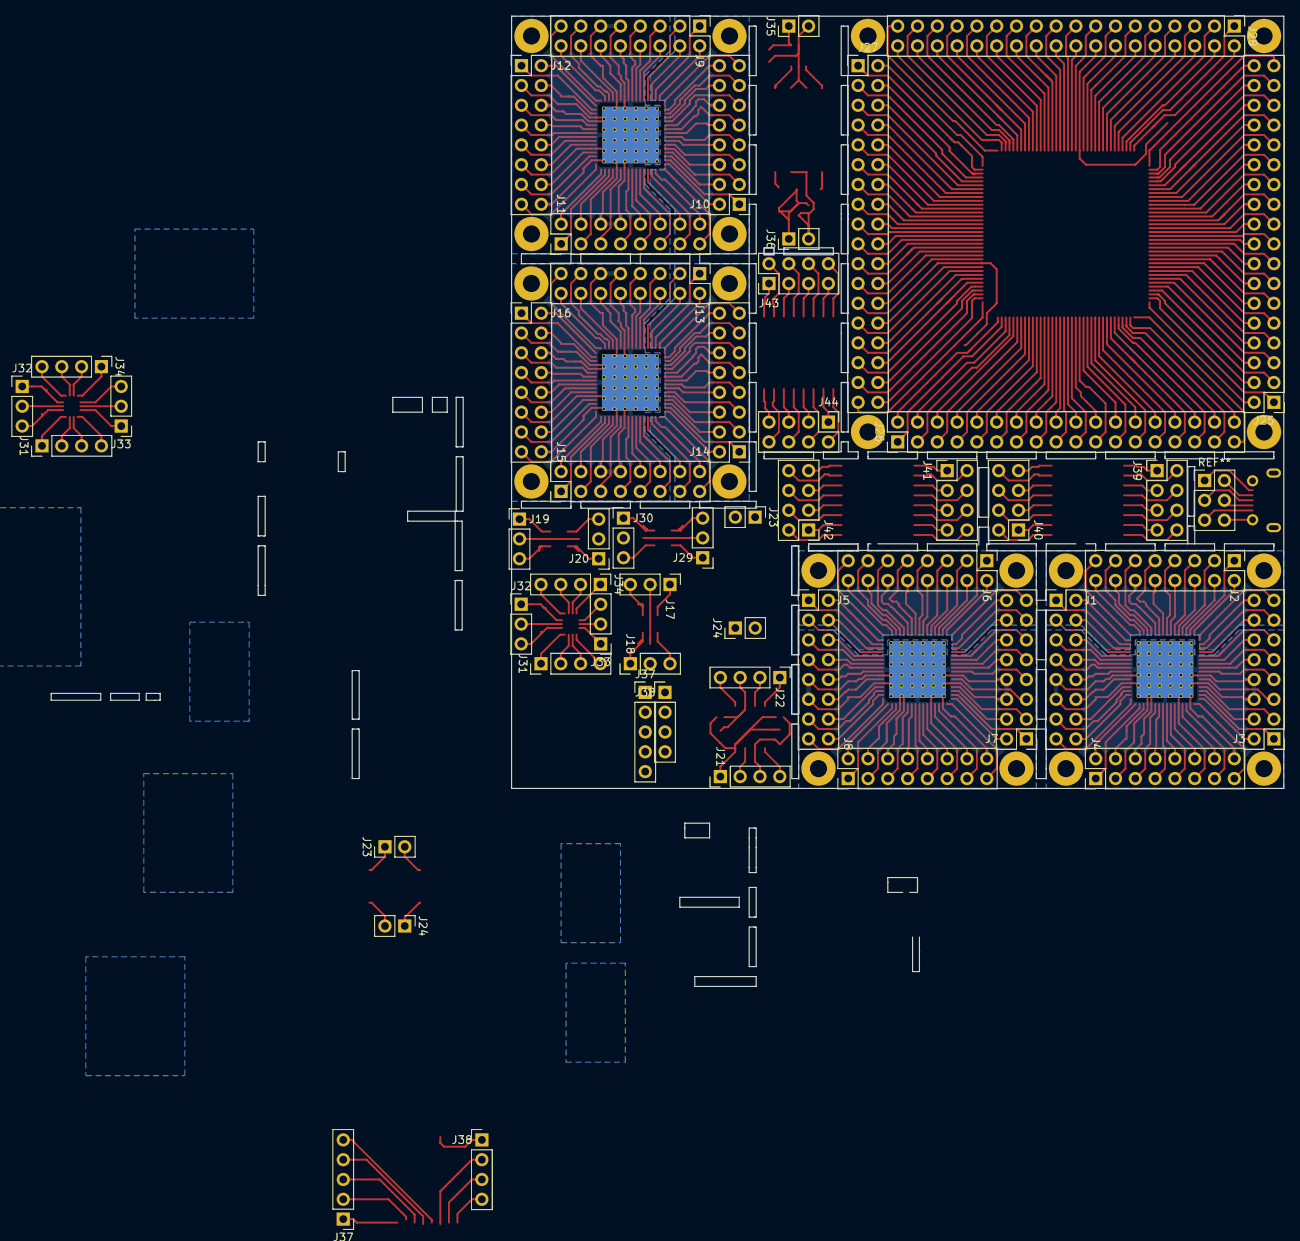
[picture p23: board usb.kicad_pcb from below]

Board: 2 copper layers, 99.1 x 99.1 mm, 198 parts (52 on the bottom side), 463 nets.

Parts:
C1, C3, C7, C9, C11, C13, C14, C15, C19, C20, C22, C24, C28, C30, C32, C34, C35, C36, C40, C41, C43, C45, C49, C51, C53, C55, C56, C57, C61, C62, C64, C66, C70, C72, C74, C76, C77, C78, C82, C83, C89, C91, C93, C94, C95, C97, C98, C99, C101, C102, C103, C105, C106, C107, C108, C111, C111#2, C112, C112#2, C114, C116, C117, C118, C119, C120, C121: 100n; C_0402_1005Metric
C2, C4, C8, C10, C12, C16, C21, C23, C25, C29, C31, C33, C37, C42, C44, C46, C50, C52, C54, C58, C63, C65, C67, C71, C73, C75, C79, C84: 1u; C_0402_1005Metric
C5, C17, C26, C38, C47, C59, C68, C80, C96: 100n; C_0603_1608Metric
C6, C18, C27, C39, C48, C60, C69, C81: 1u; C_0603_1608Metric
C85, C86, C87, C88, C100, C104, C109, C110: 2.2u; C_0603_1608Metric
C90: 22u; C_0805_2012Metric
C92, C113, C115: 10u; C_0603_1608Metric
C122: 4.7u; C_0603_1608Metric
D1, D2: D_Schottky; SOD−123
J1, J2, J3, J4, J5, J6, J7, J8, J9, J10, J11, J12, J13, J14, J15, J16: Conn_02x08_Odd_Even; PinHeader_2x08_P2.54mm_Vertical
J17, J18, J19, J20, J29, J30, J32, J32#2, J33, J33#2: Conn_01x03; PinHeader_1x03_P2.54mm_Vertical
J21, J22, J31, J31#2, J34, J34#2, J38, J38#2: Conn_01x04; PinHeader_1x04_P2.54mm_Vertical
J23, J23#2, J24, J24#2, J35, J36: Conn_01x02; PinHeader_1x02_P2.54mm_Vertical
J25, J26, J27, J28: Conn_02x18_Odd_Even; PinHeader_2x18_P2.54mm_Vertical
J37, J37#2: Conn_01x05; PinHeader_1x05_P2.54mm_Vertical
J39, J40, J41, J42, J43, J44: Conn_02x04_Odd_Even; PinHeader_2x04_P2.54mm_Vertical
T1: da2303; SMT Power Transformer
U1, U2, U3, U4: AD7779; QFN-64-1EP_9x9mm_P0.5mm_EP7.3x7.3mm_ThermalVias
U5, U6, U10: LP5907; SOT-23-5
U7: ADR4525; SOIC-8_3.9x4.9mm_P1.27mm
U8, U8#2: FXO-SM7_OSC-SMD7050_short; Oscillator_SMD_EuroQuartz_XO91-4Pin_7.0x5.0mm_HandSoldering
U9: STM32F765ZITx; LQFP-144_20x20mm_P0.5mm
U11, U11#2: LSM6DS3; Bosch_LGA-14_3x2.5mm_P0.5mm
U12: SN6505A; SOT-23-6_Handsoldering
U13, U13#2: 473521001
U14, U15, U16: ISO7341c; SOIC-16W_7.5x10.3mm_P1.27mm

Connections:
/ACCEL&GYRO/1: J31.4, J31#2.4, U11.1, U11#2.1
/ACCEL&GYRO/2: J31.3, J31#2.3, U11.2, U11#2.2
/ACCEL&GYRO/3: J31.2, J31#2.2, U11.3, U11#2.3
/ACCEL&GYRO/4: J31.1, J31#2.1, U11.4, U11#2.4
/ACCEL&GYRO/5: C111.1, C111#2.1, J32.3, J32#2.3, U11.5, U11#2.5
/ACCEL&GYRO/6: C111.2, C111#2.2, J32.2, J32#2.2, U11.6, U11#2.6
/ACCEL&GYRO/7: C112.2, C112#2.2, J32.1, J32#2.1, U11.7, U11#2.7
/ACCEL&GYRO/8: C112.1, C112#2.1, J34.4, J34#2.4, U11.8, U11#2.8
/ACCEL&GYRO/9: J34.3, J34#2.3, U11.9, U11#2.9
/ACCEL&GYRO/10: J34.2, J34#2.2, U11.10, U11#2.10
/ACCEL&GYRO/11: J34.1, J34#2.1, U11.11, U11#2.11
/ACCEL&GYRO/12: J33.3, J33#2.3, U11.12, U11#2.12
/ACCEL&GYRO/13: J33.2, J33#2.2, U11.13, U11#2.13
/ACCEL&GYRO/14: J33.1, J33#2.1, U11.14, U11#2.14
/ADC1/1: J1.15, U1.1
/ADC1/2: J1.16, U1.2
/ADC1/3: J1.13, U1.3
/ADC1/4: J1.14, U1.4
/ADC1/6: C1.2, C2.2, J1.12, U1.6
/ADC1/8: C3.2, C4.2, J1.10, U1.8
/ADC1/9: J1.7, U1.9
/ADC1/10: J1.8, U1.10
/ADC1/11: J1.5, U1.11
/ADC1/12: J1.6, U1.12
/ADC1/13: J1.3, U1.13
/ADC1/14: J1.4, U1.14
/ADC1/15: J1.1, U1.15
/ADC1/16: J1.2, U1.16
/ADC1/17: J2.15, U1.17
/ADC1/18: J2.16, U1.18
/ADC1/19: J2.13, U1.19
/ADC1/20: J2.14, U1.20
/ADC1/21: J2.11, U1.21
/ADC1/23: C7.2, C8.2, J2.9, U1.23
/ADC1/24: C5.2, C6.2, J2.10, U1.24
/ADC1/25: J2.7, U1.25
/ADC1/26: J2.8, U1.26
/ADC1/27: J2.5, U1.27
/ADC1/28: J2.6, U1.28
/ADC1/29: J2.3, U1.29
/ADC1/30: J2.4, U1.30
/ADC1/31: J2.1, U1.31
/ADC1/32: J2.2, U1.32
/ADC1/33: J3.15, U1.33
/ADC1/34: J3.16, U1.34
/ADC1/35: J3.13, U1.35
/ADC1/36: J3.14, U1.36
/ADC1/37: J3.11, U1.37
/ADC1/38: J3.12, U1.38
/ADC1/39: J3.9, U1.39
/ADC1/40: J3.10, U1.40
/ADC1/41: C9.2, C10.2, J3.7, U1.41
/ADC1/43: C11.2, C12.2, J3.5, U1.43
/ADC1/45: J3.3, U1.45
/ADC1/46: J3.4, U1.46
/ADC1/47: J3.1, U1.47
/ADC1/48: J3.2, U1.48
/ADC1/49: C13.1, J4.15, U1.49
/ADC1/51: C14.1, J4.13, U1.51
/ADC1/52: C15.2, C16.2, J4.14, U1.52
/ADC1/54: J4.12, U1.54
/ADC1/55: J4.9, U1.55
/ADC1/56: J4.10, U1.56
/ADC1/57: J4.7, U1.57
/ADC1/58: C17.2, C18.2, J4.8, U1.58
/ADC1/59: C19.1, J4.5, U1.59
/ADC1/62: C20.1, C21.1, J4.4, U1.62
/ADC1/63: J4.1, U1.63
/ADC1/64: J4.2, U1.64
/ADC2/1: J5.15, U2.1
/ADC2/2: J5.16, U2.2
/ADC2/3: J5.13, U2.3
/ADC2/4: J5.14, U2.4
/ADC2/6: C22.2, C23.2, J5.12, U2.6
/ADC2/8: C24.2, C25.2, J5.10, U2.8
/ADC2/9: J5.7, U2.9
/ADC2/10: J5.8, U2.10
/ADC2/11: J5.5, U2.11
/ADC2/12: J5.6, U2.12
/ADC2/13: J5.3, U2.13
/ADC2/14: J5.4, U2.14
/ADC2/15: J5.1, U2.15
/ADC2/16: J5.2, U2.16
/ADC2/17: J6.15, U2.17
/ADC2/18: J6.16, U2.18
/ADC2/19: J6.13, U2.19
/ADC2/20: J6.14, U2.20
/ADC2/21: J6.11, U2.21
/ADC2/23: C28.2, C29.2, J6.9, U2.23
/ADC2/24: C26.2, C27.2, J6.10, U2.24
/ADC2/25: J6.7, U2.25
/ADC2/26: J6.8, U2.26
/ADC2/27: J6.5, U2.27
/ADC2/28: J6.6, U2.28
/ADC2/29: J6.3, U2.29
/ADC2/30: J6.4, U2.30
/ADC2/31: J6.1, U2.31
/ADC2/32: J6.2, U2.32
/ADC2/33: J7.15, U2.33
/ADC2/34: J7.16, U2.34
/ADC2/35: J7.13, U2.35
/ADC2/36: J7.14, U2.36
/ADC2/37: J7.11, U2.37
/ADC2/38: J7.12, U2.38
/ADC2/39: J7.9, U2.39
/ADC2/40: J7.10, U2.40
/ADC2/41: C30.2, C31.2, J7.7, U2.41
/ADC2/43: C32.2, C33.2, J7.5, U2.43
/ADC2/45: J7.3, U2.45
/ADC2/46: J7.4, U2.46
/ADC2/47: J7.1, U2.47
/ADC2/48: J7.2, U2.48
/ADC2/49: C34.1, J8.15, U2.49
/ADC2/51: C35.1, J8.13, U2.51
/ADC2/52: C36.2, C37.2, J8.14, U2.52
/ADC2/54: J8.12, U2.54
/ADC2/55: J8.9, U2.55
/ADC2/56: J8.10, U2.56
/ADC2/57: J8.7, U2.57
/ADC2/58: C38.2, C39.2, J8.8, U2.58
/ADC2/59: C40.1, J8.5, U2.59
/ADC2/62: C41.1, C42.1, J8.4, U2.62
/ADC2/63: J8.1, U2.63
/ADC2/64: J8.2, U2.64
/ADC3/1: J9.15, U3.1
/ADC3/2: J9.16, U3.2
/ADC3/3: J9.13, U3.3
/ADC3/4: J9.14, U3.4
/ADC3/6: C43.2, C44.2, J9.12, U3.6
/ADC3/8: C45.2, C46.2, J9.10, U3.8
/ADC3/9: J9.7, U3.9
/ADC3/10: J9.8, U3.10
/ADC3/11: J9.5, U3.11
/ADC3/12: J9.6, U3.12
/ADC3/13: J9.3, U3.13
/ADC3/14: J9.4, U3.14
/ADC3/15: J9.1, U3.15
/ADC3/16: J9.2, U3.16
/ADC3/17: J10.15, U3.17
/ADC3/18: J10.16, U3.18
/ADC3/19: J10.13, U3.19
/ADC3/20: J10.14, U3.20
/ADC3/21: J10.11, U3.21
/ADC3/23: C49.2, C50.2, J10.9, U3.23
/ADC3/24: C47.2, C48.2, J10.10, U3.24
/ADC3/25: J10.7, U3.25
/ADC3/26: J10.8, U3.26
/ADC3/27: J10.5, U3.27
/ADC3/28: J10.6, U3.28
/ADC3/29: J10.3, U3.29
/ADC3/30: J10.4, U3.30
/ADC3/31: J10.1, U3.31
/ADC3/32: J10.2, U3.32
/ADC3/33: J11.15, U3.33
/ADC3/34: J11.16, U3.34
/ADC3/35: J11.13, U3.35
/ADC3/36: J11.14, U3.36
/ADC3/37: J11.11, U3.37
/ADC3/38: J11.12, U3.38
/ADC3/39: J11.9, U3.39
/ADC3/40: J11.10, U3.40
/ADC3/41: C51.2, C52.2, J11.7, U3.41
/ADC3/43: C53.2, C54.2, J11.5, U3.43
/ADC3/45: J11.3, U3.45
/ADC3/46: J11.4, U3.46
/ADC3/47: J11.1, U3.47
/ADC3/48: J11.2, U3.48
/ADC3/49: C55.1, J12.15, U3.49
/ADC3/51: C56.1, J12.13, U3.51
/ADC3/52: C57.2, C58.2, J12.14, U3.52
/ADC3/54: J12.12, U3.54
/ADC3/55: J12.9, U3.55
/ADC3/56: J12.10, U3.56
/ADC3/57: J12.7, U3.57
/ADC3/58: C59.2, C60.2, J12.8, U3.58
/ADC3/59: C61.1, J12.5, U3.59
/ADC3/62: C62.1, C63.1, J12.4, U3.62
/ADC3/63: J12.1, U3.63
/ADC3/64: J12.2, U3.64
/ADC4/1: J13.15, U4.1
/ADC4/2: J13.16, U4.2
/ADC4/3: J13.13, U4.3
/ADC4/4: J13.14, U4.4
/ADC4/6: C64.2, C65.2, J13.12, U4.6
/ADC4/8: C66.2, C67.2, J13.10, U4.8
/ADC4/9: J13.7, U4.9
/ADC4/10: J13.8, U4.10
/ADC4/11: J13.5, U4.11
/ADC4/12: J13.6, U4.12
/ADC4/13: J13.3, U4.13
/ADC4/14: J13.4, U4.14
/ADC4/15: J13.1, U4.15
/ADC4/16: J13.2, U4.16
/ADC4/17: J14.15, U4.17
/ADC4/18: J14.16, U4.18
/ADC4/19: J14.13, U4.19
/ADC4/20: J14.14, U4.20
/ADC4/21: J14.11, U4.21
/ADC4/23: C70.2, C71.2, J14.9, U4.23
/ADC4/24: C68.2, C69.2, J14.10, U4.24
/ADC4/25: J14.7, U4.25
/ADC4/26: J14.8, U4.26
/ADC4/27: J14.5, U4.27
/ADC4/28: J14.6, U4.28
/ADC4/29: J14.3, U4.29
/ADC4/30: J14.4, U4.30
/ADC4/31: J14.1, U4.31
/ADC4/32: J14.2, U4.32
/ADC4/33: J15.15, U4.33
/ADC4/34: J15.16, U4.34
/ADC4/35: J15.13, U4.35
/ADC4/36: J15.14, U4.36
/ADC4/37: J15.11, U4.37
/ADC4/38: J15.12, U4.38
/ADC4/39: J15.9, U4.39
/ADC4/40: J15.10, U4.40
/ADC4/41: C72.2, C73.2, J15.7, U4.41
/ADC4/43: C74.2, C75.2, J15.5, U4.43
/ADC4/45: J15.3, U4.45
/ADC4/46: J15.4, U4.46
/ADC4/47: J15.1, U4.47
/ADC4/48: J15.2, U4.48
/ADC4/49: C76.1, J16.15, U4.49
/ADC4/51: C77.1, J16.13, U4.51
/ADC4/52: C78.2, C79.2, J16.14, U4.52
/ADC4/54: J16.12, U4.54
/ADC4/55: J16.9, U4.55
/ADC4/56: J16.10, U4.56
/ADC4/57: J16.7, U4.57
/ADC4/58: C80.2, C81.2, J16.8, U4.58
/ADC4/59: C82.1, J16.5, U4.59
/ADC4/62: C83.1, C84.1, J16.4, U4.62
/ADC4/63: J16.1, U4.63
/ADC4/64: J16.2, U4.64
/AVDD/1: C109.1, J29.3, U10.1
/AVDD/2: C109.2, C110.2, J29.2, U10.2
/AVDD/3: J29.1, U10.3
/AVDD/4: J30.3, U10.4
/AVDD/5: C110.1, J30.1, U10.5
/CRYSTAL/1: J24.1, J24#2.1, U8.1, U8#2.1
/CRYSTAL/2: J24.2, J24#2.2, U8.2, U8#2.2
/CRYSTAL/3: J23.1, J23#2.1, U8.3, U8#2.3
/CRYSTAL/4: J23.2, J23#2.2, U8.4, U8#2.4
/IOVDD/1: C87.1, J19.3, U6.1
/IOVDD/2: C87.2, C88.2, J19.2, U6.2
/IOVDD/3: J19.1, U6.3
/IOVDD/4: J20.3, U6.4
/IOVDD/5: C88.1, J20.1, U6.5
/ISO1/1: C116.1, J39.1, U14.1
/ISO1/2: C116.2, J39.2, U14.2
/ISO1/3: J39.3, U14.3
/ISO1/4: J39.4, U14.4
/ISO1/5: J39.5, U14.5
/ISO1/6: J39.6, U14.6
/ISO1/7: J39.7, U14.7
/ISO1/8: J39.8, U14.8
/ISO1/9: J40.2, U14.9
/ISO1/10: J40.1, U14.10
/ISO1/11: J40.4, U14.11
/ISO1/12: J40.3, U14.12
/ISO1/13: J40.6, U14.13
/ISO1/14: J40.5, U14.14
/ISO1/15: C117.2, J40.8, U14.15
/ISO1/16: C117.1, J40.7, U14.16
/ISO2/1: C118.1, J41.1, U15.1
/ISO2/2: C118.2, J41.2, U15.2
/ISO2/3: J41.3, U15.3
/ISO2/4: J41.4, U15.4
/ISO2/5: J41.5, U15.5
/ISO2/6: J41.6, U15.6
/ISO2/7: J41.7, U15.7
/ISO2/8: J41.8, U15.8
/ISO2/9: J42.2, U15.9
/ISO2/10: J42.1, U15.10
/ISO2/11: J42.4, U15.11
/ISO2/12: J42.3, U15.12
/ISO2/13: J42.6, U15.13
/ISO2/14: J42.5, U15.14
/ISO2/15: C119.2, J42.8, U15.15
/ISO2/16: C119.1, J42.7, U15.16
/ISO3/1: C120.1, J43.1, U16.1
/ISO3/2: C120.2, J43.2, U16.2
/ISO3/3: J43.3, U16.3
/ISO3/4: J43.4, U16.4
/ISO3/5: J43.5, U16.5
/ISO3/6: J43.6, U16.6
/ISO3/7: J43.7, U16.7
/ISO3/8: J43.8, U16.8
/ISO3/9: J44.2, U16.9
/ISO3/10: J44.1, U16.10
/ISO3/11: J44.4, U16.11
/ISO3/12: J44.3, U16.12
/ISO3/13: J44.6, U16.13
/ISO3/14: J44.5, U16.14
/ISO3/15: C121.2, J44.8, U16.15
/ISO3/16: C121.1, J44.7, U16.16
/MCU/1: J25.35, U9.1
/MCU/2: J25.36, U9.2
/MCU/3: J25.33, U9.3
/MCU/4: J25.34, U9.4
/MCU/5: J25.31, U9.5
/MCU/6: J25.32, U9.6
/MCU/7: J25.29, U9.7
/MCU/8: J25.30, U9.8
/MCU/9: J25.27, U9.9
/MCU/10: J25.28, U9.10
/MCU/11: J25.25, U9.11
/MCU/12: J25.26, U9.12
/MCU/13: J25.23, U9.13
/MCU/14: J25.24, U9.14
/MCU/15: J25.21, U9.15
/MCU/17: C93.1, J25.19, U9.17
/MCU/18: J25.20, U9.18
/MCU/19: J25.17, U9.19
/MCU/20: J25.18, U9.20
/MCU/21: J25.15, U9.21
/MCU/22: J25.16, U9.22
/MCU/23: J25.13, U9.23
/MCU/24: J25.14, U9.24
/MCU/25: J25.11, U9.25
/MCU/26: J25.12, U9.26
/MCU/27: J25.9, U9.27
/MCU/28: J25.10, U9.28
/MCU/29: J25.7, U9.29
/MCU/30: C94.1, J25.8, U9.30
/MCU/32: C95.1, J25.6, U9.32
/MCU/33: C96.1, J25.3, U9.33
/MCU/34: J25.4, U9.34
/MCU/35: J25.1, U9.35
/MCU/36: J25.2, U9.36
/MCU/37: J26.35, U9.37
/MCU/39: C97.1, J26.33, U9.39
/MCU/40: J26.34, U9.40
/MCU/41: J26.31, U9.41
/MCU/42: J26.32, U9.42
/MCU/43: J26.29, U9.43
/MCU/44: J26.30, U9.44
/MCU/45: J26.27, U9.45
/MCU/46: J26.28, U9.46
/MCU/47: J26.25, U9.47
/MCU/48: J26.26, U9.48
/MCU/49: J26.23, U9.49
/MCU/50: J26.24, U9.50
/MCU/52: C98.1, C122.1, J26.22, U9.52
/MCU/53: J26.19, U9.53
/MCU/54: J26.20, U9.54
/MCU/55: J26.17, U9.55
/MCU/56: J26.18, U9.56
/MCU/57: J26.15, U9.57
/MCU/58: J26.16, U9.58
/MCU/59: J26.13, U9.59
/MCU/60: J26.14, U9.60
/MCU/62: C99.1, J26.12, U9.62
/MCU/63: J26.9, U9.63
/MCU/64: J26.10, U9.64
/MCU/65: J26.7, U9.65
/MCU/66: J26.8, U9.66
/MCU/67: J26.5, U9.67
/MCU/68: J26.6, U9.68
/MCU/69: J26.3, U9.69
/MCU/70: J26.4, U9.70
/MCU/71: C100.1, J26.1, U9.71
/MCU/72: C101.1, J26.2, U9.72
/MCU/73: J27.35, U9.73
/MCU/74: J27.36, U9.74
/MCU/75: J27.33, U9.75
/MCU/76: J27.34, U9.76
/MCU/77: J27.31, U9.77
/MCU/78: J27.32, U9.78
/MCU/79: J27.29, U9.79
/MCU/80: J27.30, U9.80
/MCU/81: J27.27, U9.81
/MCU/82: J27.28, U9.82
/MCU/84: C102.1, J27.26, U9.84
/MCU/85: J27.23, U9.85
/MCU/86: J27.24, U9.86
/MCU/87: J27.21, U9.87
/MCU/88: J27.22, U9.88
/MCU/89: J27.19, U9.89
/MCU/90: J27.20, U9.90
/MCU/91: J27.17, U9.91
/MCU/92: J27.18, U9.92
/MCU/93: J27.15, U9.93
/MCU/95: C103.1, J27.13, U9.95
/MCU/96: J27.14, U9.96
/MCU/97: J27.11, U9.97
/MCU/98: J27.12, U9.98
/MCU/99: J27.9, U9.99
/MCU/100: J27.10, U9.100
/MCU/101: J27.7, U9.101
/MCU/102: J27.8, U9.102
/MCU/103: J27.5, U9.103
/MCU/104: J27.6, U9.104
/MCU/105: J27.3, U9.105
/MCU/106: C104.1, J27.4, U9.106
/MCU/108: C105.1, J27.2, U9.108
/MCU/109: J28.35, U9.109
/MCU/110: J28.36, U9.110
/MCU/111: J28.33, U9.111
/MCU/112: J28.34, U9.112
/MCU/113: J28.31, U9.113
/MCU/114: J28.32, U9.114
/MCU/115: J28.29, U9.115
/MCU/116: J28.30, U9.116
/MCU/117: J28.27, U9.117
/MCU/118: J28.28, U9.118
/MCU/119: J28.25, U9.119
/MCU/121: C106.1, J28.23, U9.121
/MCU/122: J28.24, U9.122
/MCU/123: J28.21, U9.123
/MCU/124: J28.22, U9.124
/MCU/125: J28.19, U9.125
/MCU/126: J28.20, U9.126
/MCU/127: J28.17, U9.127
/MCU/128: J28.18, U9.128
/MCU/129: J28.15, U9.129
/MCU/131: C107.1, J28.13, U9.131
/MCU/132: J28.14, U9.132
/MCU/133: J28.11, U9.133
/MCU/134: J28.12, U9.134
/MCU/135: J28.9, U9.135
/MCU/136: J28.10, U9.136
/MCU/137: J28.7, U9.137
/MCU/138: J28.8, U9.138
/MCU/139: J28.5, U9.139
/MCU/140: J28.6, U9.140
/MCU/141: J28.3, U9.141
/MCU/142: J28.4, U9.142
/MCU/143: J28.1, U9.143
/MCU/144: C108.1, J28.2, U9.144
/POWER/1: C113.1, J35.1, U12.4
/POWER/2: C113.2, J35.2, T1.2, T1.3, U12.2, U12.5
/POWER/3: C114.1, C115.1, D1.1, D2.1, J36.1
/POWER/4: C114.2, C115.2, J36.2, T1.6, T1.7
/REF/1: J21.4, U7.1
/REF/2: C89.1, C90.1, J21.3, U7.2
/REF/3: J21.2, U7.3
/REF/4: C89.2, C90.2, C91.2, C92.2, J21.1, U7.4
/REF/5: J22.4, U7.5
/REF/6: C91.1, C92.1, J22.3, U7.6
/REF/7: J22.2, U7.7
/REF/8: J22.1, U7.8
/SD/1: J37.1, J37#2.1, U13.1, U13#2.1
/SD/2: J37.2, J37#2.2, U13.2, U13#2.2
/SD/3: J37.3, J37#2.3, U13.3, U13#2.3
/SD/4: J37.4, J37#2.4, U13.4, U13#2.4
/SD/5: J37.5, J37#2.5, U13.5, U13#2.5
/SD/6: J38.2, J38#2.2, U13.6, U13#2.6
/SD/7: J38.3, J38#2.3, U13.7, U13#2.7
/SD/8: J38.4, J38#2.4, U13.8, U13#2.8
/SD/9: J38.1, J38#2.1, U13.9, U13#2.9
/VDD/1: C85.1, J17.3, U5.1
/VDD/2: C85.2, C86.2, J17.2, U5.2
/VDD/3: J17.1, U5.3
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

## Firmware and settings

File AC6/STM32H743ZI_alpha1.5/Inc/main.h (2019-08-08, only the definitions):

#define ADC2_DRDY_Pin GPIO_PIN_13
#define ADC2_DRDY_GPIO_Port GPIOC
#define ADC2_START_Pin GPIO_PIN_4
#define ADC2_START_GPIO_Port GPIOF
#define ADC2_RESET_Pin GPIO_PIN_5
#define ADC2_RESET_GPIO_Port GPIOF
#define ISO_USB_PIN_Pin GPIO_PIN_7
#define ISO_USB_PIN_GPIO_Port GPIOF
#define ADC3_DRDY_Pin GPIO_PIN_10
#define ADC3_DRDY_GPIO_Port GPIOF
#define ADC3_START_Pin GPIO_PIN_5
#define ADC3_START_GPIO_Port GPIOC
#define ADC1_DRDY_Pin GPIO_PIN_0
#define ADC1_DRDY_GPIO_Port GPIOB
#define ADC1_DRDY_EXTI_IRQn EXTI0_IRQn
#define ADC3_RESET_Pin GPIO_PIN_1
#define ADC3_RESET_GPIO_Port GPIOB
#define BOOT1_Pin GPIO_PIN_2
#define BOOT1_GPIO_Port GPIOB
#define ADC4_START_Pin GPIO_PIN_2
#define ADC4_START_GPIO_Port GPIOG
#define ADC4_RESET_Pin GPIO_PIN_3
#define ADC4_RESET_GPIO_Port GPIOG
#define ADC4_DRDY_Pin GPIO_PIN_4
#define ADC4_DRDY_GPIO_Port GPIOG
#define SDMMC1_DETECT_Pin GPIO_PIN_7
#define SDMMC1_DETECT_GPIO_Port GPIOC
#define ADC1_START_Pin GPIO_PIN_4
#define ADC1_START_GPIO_Port GPIOD
#define ADC1_RESET_Pin GPIO_PIN_5
#define ADC1_RESET_GPIO_Port GPIOD
#define ACC_INT1_Pin GPIO_PIN_8
#define ACC_INT1_GPIO_Port GPIOB
#define ACC_SDO_SAO_Pin GPIO_PIN_9
#define ACC_SDO_SAO_GPIO_Port GPIOB
#define ACC_INT2_Pin GPIO_PIN_1
#define ACC_INT2_GPIO_Port GPIOE
#define AD_DRDY_Pin ADC1_DRDY_Pin
#define AD_DRDY_GPIO_Port ADC1_DRDY_GPIO_Port
#define SPI1_NSS_Pin GPIO_PIN_4
#define SPI1_NSS_GPIO_Port GPIOA
#define SPI2_NSS_Pin GPIO_PIN_12
#define SPI2_NSS_GPIO_Port GPIOB
#define SPI3_NSS_Pin GPIO_PIN_10
#define SPI3_NSS_GPIO_Port GPIOA
#define SPI4_NSS_Pin GPIO_PIN_8
#define SPI4_NSS_GPIO_Port GPIOG
#define SPI6_NSS_Pin GPIO_PIN_11
#define SPI6_NSS_GPIO_Port GPIOE
#define FREESMARTEEG_OPENBCI                   (1LL<<0)
#define FREESMARTEEG_PROCESSING                (1LL<<1)
#define FREESMARTEEG_CRC                       (1LL<<2)
#define FREESMARTEEG_TEXT                      (1LL<<3)
#define FREESMARTEEG_SAMPLECOUNT               (1LL<<4)
#define FREESMARTEEG_BLINK                     (1LL<<5)
#define FREESMARTEEG_FFT                       (1LL<<6)
#define FREESMARTEEG_DIF                       (1LL<<7)
#define FREESMARTEEG_TEST_COUNTER              (1LL<<8)
#define FREESMARTEEG_TEXT_UART1                (1LL<<9)
#define FREESMARTEEG_OPENVIBE_TELNET           (1LL<<10)
#define FREESMARTEEG_ARDUINO_MEGA_DISPLAY      (1LL<<11)
#define FREESMARTEEG_OPENVIBE_TELNET_PACKET    (1LL<<12)
#define FREESMARTEEG_OPENBCI_TELNET_PACKET     (1LL<<13)
#define FREESMARTEEG_OPENVIBE_FREEEEG32        (1LL<<14)
#define FREESMARTEEG_CHANNELS_STATE            (1LL<<15)
#define FREESMARTEEG_FFT_DISPLAY               (1LL<<16)
#define FREESMARTEEG_TEST_BLINK                (1LL<<17)
#define FREESMARTEEG_STABLE_CRC                (1LL<<18)
#define FREESMARTEEG_TEST_COUNTER2             (1LL<<19)
#define FREESMARTEEG_TEST_BLINK2               (1LL<<20)
#define FREESMARTEEG_DEVICES_STATE             (1LL<<21)
#define FREESMARTEEG_TEXT_USB                  (1LL<<22)
#define FREESMARTEEG_TEXT_SDCARD               (1LL<<23)
#define FREESMARTEEG_SDCARD_TEXT               (1LL<<24)
#define FREESMARTEEG_TEST_SDCARD               (1LL<<25)
#define FREESMARTEEG_WRITE_SDCARD              (1LL<<26)
#define FREESMARTEEG_SDCARD_OPENVIBE           (1LL<<27)
#define FREESMARTEEG_WRITE_SDCARD_OPENVIBE     (1LL<<28)
#define FREESMARTEEG_SDCARD_FORMAT             (1LL<<29)
#define FREESMARTEEG_TEXT_UART7                (1LL<<30)
#define FREESMARTEEG_DATA_TEXT_UART7           (1LL<<31)
#define FREESMARTEEG_DATA_OPENVIBE_FREEEEG32   (1LL<<32)
#define FREESMARTEEG_TEST_ACCGYR_SPI3          (1LL<<33)
#define FREESMARTEEG_OPENVIBE_FREEEEG32_CUSTOM (1LL<<34)
#define FREESMARTEEG_DATA_OPENVIBE_FREEEEG32_CUSTOM (1LL<<35)
#define FREESMARTEEG_DATA_TEXT_UART7_INT       (1LL<<36)
#define FREESMARTEEG_DATA_OPENVIBE_FREEEEG32_CUSTOM_INT (1LL<<37)
#define FREESMARTEEG_SPI_OPENVIBE_FREEEEG32_CUSTOM_INT (1LL<<38)
#define FREESMARTEEG_TEXT_UART7_SAI2B_TIMER     (1LL<<40)
#define FREESMARTEEG_OPENVIBE_FREEEEG32_UART7_SAI2B_TIMER     (1LL<<41)
#define FREESMARTEEG_DMA_UART7_SAI2B_TIMER     (1LL<<42)
#define FREESMARTEEG_SAI_TEXT_UART7_INT       (1LL<<43)
#define FREESMARTEEG_SAI_OPENVIBE_FREEEEG32_CUSTOM_INT (1LL<<44)
#define FREESMARTEEG_SAI_TEXT_UART7     (1LL<<45)
#define FREESMARTEEG_SAI_OPENVIBE_FREEEEG32_CUSTOM (1LL<<46)
#define FREESMARTEEG_I2S_TEXT_UART7_INT     (1LL<<47)
#define FREESMARTEEG_I2S_OPENVIBE_FREEEEG32_CUSTOM_INT (1LL<<48)
#define FREESMARTEEG_I2S_TEXT_UART7     (1LL<<49)
#define FREESMARTEEG_I2S_OPENVIBE_FREEEEG32_CUSTOM (1LL<<50)
#define FREESMARTEEG_SPI_TEXT_UART7_INT (1LL<<51)
#define FREESMARTEEG_SAI_TEXT_UART7_INT_DMA       (1LL<<52)
#define FREESMARTEEG_SAI_OPENVIBE_FREEEEG32_CUSTOM_INT_DMA (1LL<<53)
#define FREESMARTEEG_OUT FREESMARTEEG_SAI_OPENVIBE_FREEEEG32_CUSTOM_INT
#define FREESMARTEEG_ADC_NONE (0)
#define FREESMARTEEG_ADC_SPI_READ (1LL<<0)
#define FREESMARTEEG_ADC_DATA_READ (1LL<<1)
#define FREESMARTEEG_ADC_DATA_READ_INT (1LL<<2)
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

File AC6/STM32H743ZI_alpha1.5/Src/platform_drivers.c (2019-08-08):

/***************************************************************************//**
* @file platform_drivers.c
* @brief Implementation of Platform Drivers.
* @author DBogdan (dragos.bogdan@analog.com)
********************************************************************************
* Copyright 2014-2015(c) Analog Devices, Inc.
*
* All rights reserved.
*
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
* THIS SOFTWARE IS PROVIDED BY ANALOG DEVICES "AS IS" AND ANY EXPRESS OR
* IMPLIED WARRANTIES, INCLUDING, BUT NOT LIMITED TO, NON-INFRINGEMENT,
* MERCHANTABILITY AND FITNESS FOR A PARTICULAR PURPOSE ARE DISCLAIMED.
* IN NO EVENT SHALL ANALOG DEVICES BE LIABLE FOR ANY DIRECT, INDIRECT,
* INCIDENTAL, SPECIAL, EXEMPLARY, OR CONSEQUENTIAL DAMAGES (INCLUDING, BUT NOT
* LIMITED TO, INTELLECTUAL PROPERTY RIGHTS, PROCUREMENT OF SUBSTITUTE GOODS OR
* SERVICES; LOSS OF USE, DATA, OR PROFITS; OR BUSINESS INTERRUPTION) HOWEVER
* CAUSED AND ON ANY THEORY OF LIABILITY, WHETHER IN CONTRACT, STRICT LIABILITY,
* OR TORT (INCLUDING NEGLIGENCE OR OTHERWISE) ARISING IN ANY WAY OUT OF THE USE
* OF THIS SOFTWARE, EVEN IF ADVISED OF THE POSSIBILITY OF SUCH DAMAGE.
*******************************************************************************/

/******************************************************************************/
/***************************** Include Files **********************************/
/******************************************************************************/

#include "stm32h7xx_hal.h"

#include "main.h"
#include "platform_drivers.h"

/******************************************************************************/
/************************ Variables Definitions *******************************/
/******************************************************************************/


#ifdef _XPARAMETERS_PS_H_
XSpiPs_Config	*spi_config;
XSpiPs			spi_instance;
XGpioPs_Config	*gpio_config;
XGpioPs			gpio_instance;
uint8_t			spi_decoded_cs = 0;
#else
//XSpi_Config		*spi_config;
//XSpi			spi_instance;
//XGpio_Config	*gpio_config;
//XGpio			gpio_instance;

//SPI_HandleTypeDef* hhspi1;
//UART_HandleTypeDef* huart;

#endif

/***************************************************************************//**
* @brief spi_init
*******************************************************************************/
int32_t spi_init(SPI_HandleTypeDef* hspi/*uint32_t device_id,
				 uint8_t clk_pha,
				 uint8_t clk_pol*/)
{
	uint32_t base_addr	 = 0;
	uint32_t spi_options = 0;

#ifdef _XPARAMETERS_PS_H_
	spi_config = XSpiPs_LookupConfig(device_id);

	base_addr = spi_config->BaseAddress;
	XSpiPs_CfgInitialize(&spi_instance, spi_config, base_addr);

	spi_options = XSPIPS_MASTER_OPTION |
			(clk_pol ? XSPIPS_CLK_ACTIVE_LOW_OPTION : 0) |
			(clk_pha ? XSPIPS_CLK_PHASE_1_OPTION : 0) |
			(spi_decoded_cs ? XSPIPS_DECODE_SSELECT_OPTION : 0) |
			XSPIPS_FORCE_SSELECT_OPTION;
	XSpiPs_SetOptions(&spi_instance, spi_options);

	XSpiPs_SetClkPrescaler(&spi_instance, XSPIPS_CLK_PRESCALE_32);

	/* FIXME: Temporary 15.2 Fix */
	XSpiPs_CfgInitialize(&spi_instance, spi_config, base_addr);

	XSpiPs_SetOptions(&spi_instance, spi_options);

	XSpiPs_SetClkPrescaler(&spi_instance, XSPIPS_CLK_PRESCALE_32);
#else
//	hhspi1 = hspi;
/*
  hspi1.Instance = SPI1;
  hspi1.Init.Mode = SPI_MODE_MASTER;
  hspi1.Init.Direction = SPI_DIRECTION_2LINES;
  hspi1.Init.DataSize = SPI_DATASIZE_8BIT;
  hspi1.Init.CLKPolarity = SPI_POLARITY_LOW;
  hspi1.Init.CLKPhase = SPI_PHASE_1EDGE;
  hspi1.Init.NSS = SPI_NSS_HARD_OUTPUT;
//  hspi1.Init.NSS = SPI_NSS_SOFT;
  hspi1.Init.BaudRatePrescaler = SPI_BAUDRATEPRESCALER_8;
  hspi1.Init.FirstBit = SPI_FIRSTBIT_MSB;
  hspi1.Init.TIMode = SPI_TIMODE_DISABLED;
  hspi1.Init.CRCCalculation = SPI_CRCCALCULATION_DISABLED;

	HAL_SPI_Init(hspi1);*/
//  HAL_SPI_MspInit(hspi);

/*	XSpi_Initialize(&spi_instance, device_id);

	XSpi_Stop(&spi_instance);

	spi_config = XSpi_LookupConfig(device_id);

	base_addr = spi_config->BaseAddress;
	XSpi_CfgInitialize(&spi_instance, spi_config, base_addr);

	spi_options = XSP_MASTER_OPTION |
				  (clk_pol ? XSP_CLK_ACTIVE_LOW_OPTION : 0) |
				  (clk_pha ? XSP_CLK_PHASE_1_OPTION : 0) |
				  XSP_MANUAL_SSELECT_OPTION;
	XSpi_SetOptions(&spi_instance, spi_options);

	XSpi_Start(&spi_instance);

	XSpi_IntrGlobalDisable(&spi_instance);*/
/*
	GPIO_InitTypeDef port;
	SPI_InitTypeDef spi;

  //Тут абсолютно вся инициализация
  RCC_APB2PeriphClockCmd(RCC_APB2Periph_GPIOA, ENABLE);
//  RCC_APB2PeriphClockCmd(RCC_APB2Periph_GPIOB, ENABLE);
  RCC_APB2PeriphClockCmd(RCC_APB2Periph_SPI1, ENABLE);
//  RCC_APB1PeriphClockCmd(RCC_APB1Periph_SPI2, ENABLE);
  RCC_APB2PeriphClockCmd(RCC_APB2Periph_AFIO, ENABLE);
*/

//  GPIO_PinRemapConfig(GPIO_Remap_SWJ_JTAGDisable, ENABLE); // Requires AFIO clock enabled, Map JTAG Off pins PB3,4,5, SWD still viable on PA13,14
//  GPIO_PinRemapConfig(GPIO_Remap_SPI1, ENABLE);

//  port.GPIO_Mode = GPIO_Mode_Out_PP;
//  port.GPIO_Pin = GPIO_Pin_12 | GPIO_Pin_13 | GPIO_Pin_14 | GPIO_Pin_15;
//  port.GPIO_Mode = GPIO_Mode_Out_PP;
/*  port.GPIO_Mode = GPIO_Mode_AF_PP;
port.GPIO_Pin = GPIO_Pin_3 | GPIO_Pin_5;
//  port.GPIO_Pin = GPIO_Pin_3 | GPIO_Pin_4 | GPIO_Pin_5;
port.GPIO_Speed = GPIO_Speed_50MHz;
GPIO_Init(GPIOB, &port);

port.GPIO_Mode = GPIO_Mode_IN_FLOATING;
port.GPIO_Pin = GPIO_Pin_4;
port.GPIO_Speed = GPIO_Speed_50MHz;
GPIO_Init(GPIOB, &port);

port.GPIO_Mode = GPIO_Mode_AF_PP;
port.GPIO_Pin = GPIO_Pin_15;
port.GPIO_Speed = GPIO_Speed_50MHz;
GPIO_Init(GPIOA, &port);

  SPI_I2S_DeInit(SPI1);

port.GPIO_Mode = GPIO_Mode_Out_PP;
port.GPIO_Pin = GPIO_Pin_4;
port.GPIO_Speed = GPIO_Speed_50MHz;
GPIO_Init(GPIOA, &port);*/

//  SPI_I2S_DeInit(SPI1);
/*
  port.GPIO_Mode = GPIO_Mode_AF_PP;
//  port.GPIO_Mode = GPIO_Mode_Out_PP;
  port.GPIO_Pin = GPIO_Pin_5 | GPIO_Pin_7;// | GPIO_Pin_6;
//  port.GPIO_Pin = GPIO_Pin_4 | GPIO_Pin_5 | GPIO_Pin_7 | = GPIO_Pin_6;
//  port.GPIO_Speed = GPIO_Speed_2MHz;
    port.GPIO_Speed = GPIO_Speed_50MHz;
  GPIO_Init(GPIOA, &port);

//  port.GPIO_Mode = GPIO_Mode_AF_PP;
  port.GPIO_Mode = GPIO_Mode_Out_PP;
  port.GPIO_Pin = GPIO_Pin_4;
//  port.GPIO_Speed = GPIO_Speed_2MHz;
    port.GPIO_Speed = GPIO_Speed_50MHz;
  GPIO_Init(GPIOA, &port);
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

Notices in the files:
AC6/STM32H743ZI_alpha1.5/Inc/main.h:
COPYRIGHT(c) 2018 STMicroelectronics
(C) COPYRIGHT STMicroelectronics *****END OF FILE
